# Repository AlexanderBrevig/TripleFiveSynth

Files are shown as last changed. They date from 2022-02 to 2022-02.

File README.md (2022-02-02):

# TripleFiveSynth

    Work In Progress!

A simple idea of using a 555 timer per note in a synth.

## `/src/main.rs`

This will generate appropriate capacitor and trim values for each note.

See the output in [tune_triple_fives.txt](https://raw.githubusercontent.com/alexanderbrevig/TripleFiveSynth/tune_triple_fives.txt) for details.

## 555 Configuration

The plan is to have one of these voices per note:
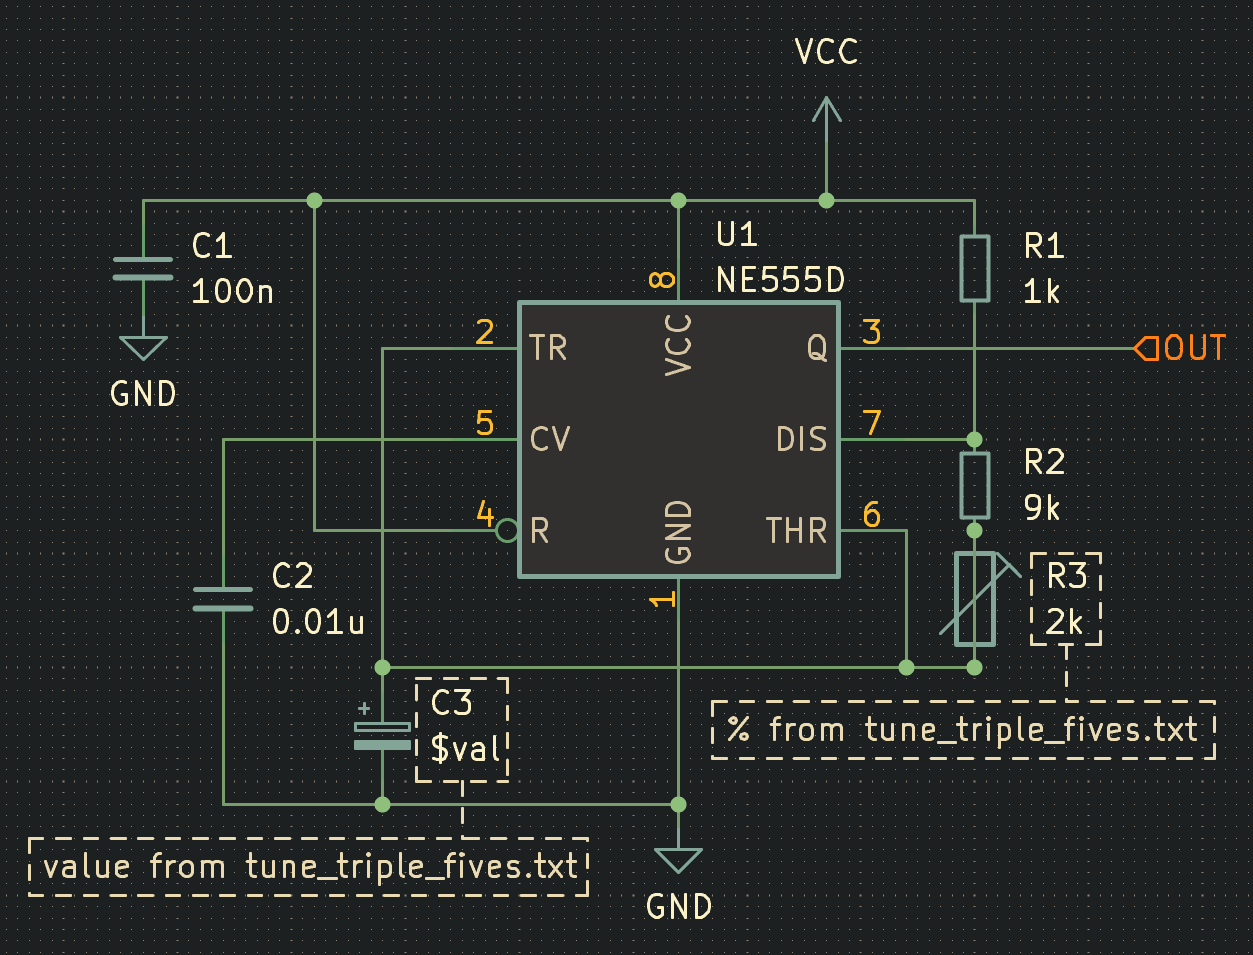
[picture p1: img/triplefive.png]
555 voice


## Example tuning for 440Hz

Per the line in `tune_triple_fives.txt` we get:

> 0440.00Hz => 150.00nF	Trim => 1431.9Ω -> 71.60%

This means, our `C3` should be `150nF`, and `R3` at approx `71.6%`.

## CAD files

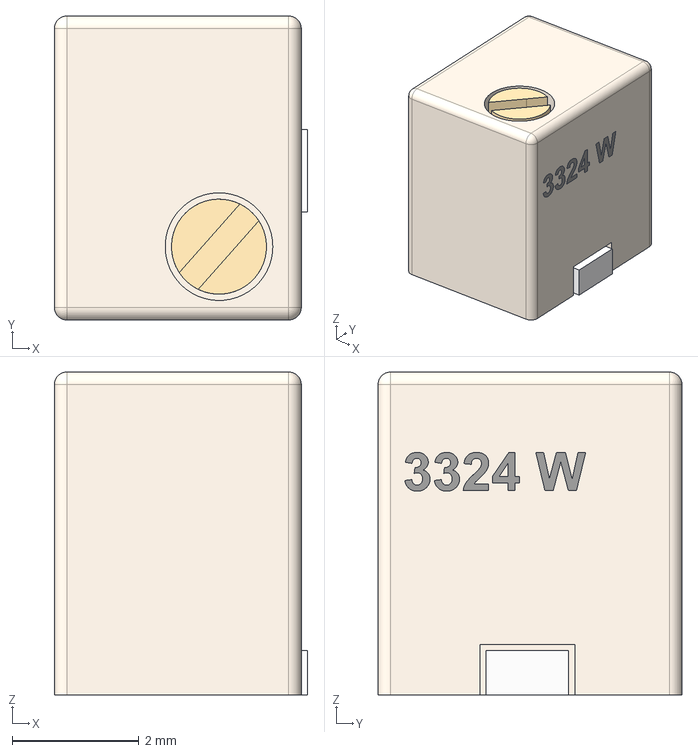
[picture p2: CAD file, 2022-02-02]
step/Bourns 3324W Trimpot.step
4.00 x 4.80 x 5.10 mm

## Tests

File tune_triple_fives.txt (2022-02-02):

0016.35Hz => 003.90uF	Trim => 1818.4Ω -> 90.92%
0017.32Hz => 003.90uF	Trim => 1184.3Ω -> 59.21%
0018.35Hz => 003.60uF	Trim => 1424.8Ω -> 71.24%
0019.45Hz => 003.30uF	Trim => 1743.8Ω -> 87.19%
0020.60Hz => 003.30uF	Trim => 1116.0Ω -> 55.80%
0021.83Hz => 003.00uF	Trim => 1519.4Ω -> 75.97%
0023.12Hz => 003.00uF	Trim => 0904.5Ω -> 45.23%
0024.50Hz => 002.70uF	Trim => 1409.2Ω -> 70.46%
0025.96Hz => 002.70uF	Trim => 0795.6Ω -> 39.78%
0027.50Hz => 002.40uF	Trim => 1433.8Ω -> 71.69%
0029.14Hz => 002.20uF	Trim => 1756.3Ω -> 87.82%
0030.87Hz => 002.20uF	Trim => 1125.4Ω -> 56.27%
0032.70Hz => 002.00uF	Trim => 1533.8Ω -> 76.69%
0034.65Hz => 002.00uF	Trim => 0912.7Ω -> 45.64%
0036.71Hz => 001.80uF	Trim => 1420.4Ω -> 71.02%
0038.89Hz => 001.80uF	Trim => 0808.1Ω -> 40.41%
0041.20Hz => 001.60uF	Trim => 1446.4Ω -> 72.32%
0043.65Hz => 001.50uF	Trim => 1520.7Ω -> 76.04%
0046.25Hz => 001.50uF	Trim => 0901.1Ω -> 45.06%
0049.00Hz => 001.30uF	Trim => 1827.6Ω -> 91.38%
0051.91Hz => 001.30uF	Trim => 1192.6Ω -> 59.63%
0055.00Hz => 001.20uF	Trim => 1432.8Ω -> 71.64%
0058.27Hz => 001.10uF	Trim => 1757.3Ω -> 87.87%
0061.74Hz => 001.10uF	Trim => 1124.6Ω -> 56.23%
0065.41Hz => 001.00uF	Trim => 1531.2Ω -> 76.56%
0069.30Hz => 001.00uF	Trim => 0912.0Ω -> 45.60%
0069.30Hz => 910.00nF	Trim => 1941.7Ω -> 97.09%
0073.42Hz => 001.00uF	Trim => 0327.7Ω -> 16.39%
0073.42Hz => 910.00nF	Trim => 1299.6Ω -> 64.98%
0077.78Hz => 820.00nF	Trim => 1813.1Ω -> 90.66%
0082.41Hz => 820.00nF	Trim => 1177.4Ω -> 58.87%
0087.31Hz => 750.00nF	Trim => 1518.8Ω -> 75.94%
0092.50Hz => 680.00nF	Trim => 1971.2Ω -> 98.56%
0098.00Hz => 680.00nF	Trim => 1327.3Ω -> 66.37%
0103.83Hz => 620.00nF	Trim => 1708.3Ω -> 85.42%
0110.00Hz => 620.00nF	Trim => 1079.6Ω -> 53.98%
0116.54Hz => 560.00nF	Trim => 1555.8Ω -> 77.79%
0123.47Hz => 510.00nF	Trim => 1958.3Ω -> 97.92%
0130.81Hz => 510.00nF	Trim => 1315.3Ω -> 65.77%
0138.59Hz => 470.00nF	Trim => 1577.0Ω -> 78.85%
0146.83Hz => 430.00nF	Trim => 1927.9Ω -> 96.40%
0155.56Hz => 430.00nF	Trim => 1286.5Ω -> 64.33%
0164.81Hz => 390.00nF	Trim => 1725.3Ω -> 86.27%
0174.61Hz => 360.00nF	Trim => 1978.3Ω -> 98.92%
0185.00Hz => 360.00nF	Trim => 1333.6Ω -> 66.68%
0196.00Hz => 330.00nF	Trim => 1655.2Ω -> 82.76%
0207.65Hz => 330.00nF	Trim => 1029.3Ω -> 51.46%
0220.00Hz => 300.00nF	Trim => 1432.0Ω -> 71.60%
0233.08Hz => 270.00nF	Trim => 1965.0Ω -> 98.25%
0246.94Hz => 270.00nF	Trim => 1321.5Ω -> 66.07%
0261.63Hz => 240.00nF	Trim => 1990.6Ω -> 99.53%
0277.18Hz => 240.00nF	Trim => 1346.0Ω -> 67.30%
0293.66Hz => 220.00nF	Trim => 1668.0Ω -> 83.40%
0311.13Hz => 220.00nF	Trim => 1040.9Ω -> 52.05%
0329.63Hz => 200.00nF	Trim => 1444.2Ω -> 72.21%
0349.23Hz => 180.00nF	Trim => 1977.8Ω -> 98.89%
0369.99Hz => 180.00nF	Trim => 1333.7Ω -> 66.69%
0392.00Hz => 180.00nF	Trim => 0725.4Ω -> 36.27%
0415.30Hz => 160.00nF	Trim => 1358.2Ω -> 67.91%
0440.00Hz => 150.00nF	Trim => 1431.9Ω -> 71.60%
0466.16Hz => 150.00nF	Trim => 0818.4Ω -> 40.92%
0493.88Hz => 130.00nF	Trim => 1737.6Ω -> 86.88%
0523.25Hz => 120.00nF	Trim => 1990.8Ω -> 99.54%
0554.37Hz => 120.00nF	Trim => 1345.7Ω -> 67.29%
0587.33Hz => 110.00nF	Trim => 1667.7Ω -> 83.39%
0622.25Hz => 110.00nF	Trim => 1041.0Ω -> 52.05%
0659.25Hz => 100.00nF	Trim => 1444.3Ω -> 72.22%
0698.46Hz => 091.00nF	Trim => 1851.5Ω -> 92.58%
0698.46Hz => 100.00nF	Trim => 0829.9Ω -> 41.50%
0739.99Hz => 091.00nF	Trim => 1214.5Ω -> 60.73%
0739.99Hz => 100.00nF	Trim => 0250.2Ω -> 12.51%
0783.99Hz => 082.00nF	Trim => 1723.1Ω -> 86.16%
0830.61Hz => 082.00nF	Trim => 1093.2Ω -> 54.66%
0880.00Hz => 075.00nF	Trim => 1431.8Ω -> 71.59%
0932.33Hz => 068.00nF	Trim => 1880.4Ω -> 94.02%
0987.77Hz => 068.00nF	Trim => 1241.7Ω -> 62.09%
1046.50Hz => 062.00nF	Trim => 1620.0Ω -> 81.00%
1108.73Hz => 062.00nF	Trim => 0995.9Ω -> 49.80%
1174.66Hz => 056.00nF	Trim => 1468.2Ω -> 73.41%
1244.51Hz => 051.00nF	Trim => 1867.6Ω -> 93.38%
1318.51Hz => 051.00nF	Trim => 1229.6Ω -> 61.48%
1396.91Hz => 047.00nF	Trim => 1489.3Ω -> 74.46%
1479.98Hz => 043.00nF	Trim => 1837.4Ω -> 91.87%
1567.98Hz => 043.00nF	Trim => 1201.1Ω -> 60.05%
1661.22Hz => 039.00nF	Trim => 1636.4Ω -> 81.82%
1760.00Hz => 036.00nF	Trim => 1887.3Ω -> 94.37%
1864.66Hz => 036.00nF	Trim => 1248.2Ω -> 62.41%
1975.53Hz => 033.00nF	Trim => 1567.2Ω -> 78.36%
2093.00Hz => 030.00nF	Trim => 1990.7Ω -> 99.54%
2217.46Hz => 030.00nF	Trim => 1345.8Ω -> 67.29%
2349.32Hz => 027.00nF	Trim => 1874.5Ω -> 93.73%
2489.02Hz => 027.00nF	Trim => 1236.1Ω -> 61.81%
2637.02Hz => 024.00nF	Trim => 1900.2Ω -> 95.01%
2793.83Hz => 024.00nF	Trim => 1260.3Ω -> 63.02%
2959.96Hz => 022.00nF	Trim => 1579.7Ω -> 78.99%
3135.96Hz => 022.00nF	Trim => 0957.9Ω -> 47.90%
3322.44Hz => 020.00nF	Trim => 1358.0Ω -> 67.90%
3520.00Hz => 018.00nF	Trim => 1887.3Ω -> 94.37%
3729.31Hz => 018.00nF	Trim => 1248.2Ω -> 62.41%
3951.07Hz => 016.00nF	Trim => 1913.1Ω -> 95.65%
4186.01Hz => 015.00nF	Trim => 1990.7Ω -> 99.54%
4434.92Hz => 015.00nF	Trim => 1345.8Ω -> 67.29%
4698.63Hz => 015.00nF	Trim => 0737.0Ω -> 36.85%
4978.03Hz => 013.00nF	Trim => 1649.0Ω -> 82.45%
5274.04Hz => 012.00nF	Trim => 1900.2Ω -> 95.01%
5587.65Hz => 012.00nF	Trim => 1260.3Ω -> 63.02%
5919.91Hz => 011.00nF	Trim => 1579.7Ω -> 78.99%
6271.93Hz => 011.00nF	Trim => 0957.9Ω -> 47.90%
6644.88Hz => 010.00nF	Trim => 1358.0Ω -> 67.90%
7040.00Hz => 009.10nF	Trim => 1762.2Ω -> 88.11%
7040.00Hz => 010.00nF	Trim => 0748.6Ω -> 37.43%
7458.62Hz => 009.10nF	Trim => 1130.1Ω -> 56.50%
7458.62Hz => 010.00nF	Trim => 0173.4Ω -> 08.67%
7902.13Hz => 008.20nF	Trim => 1634.7Ω -> 81.74%

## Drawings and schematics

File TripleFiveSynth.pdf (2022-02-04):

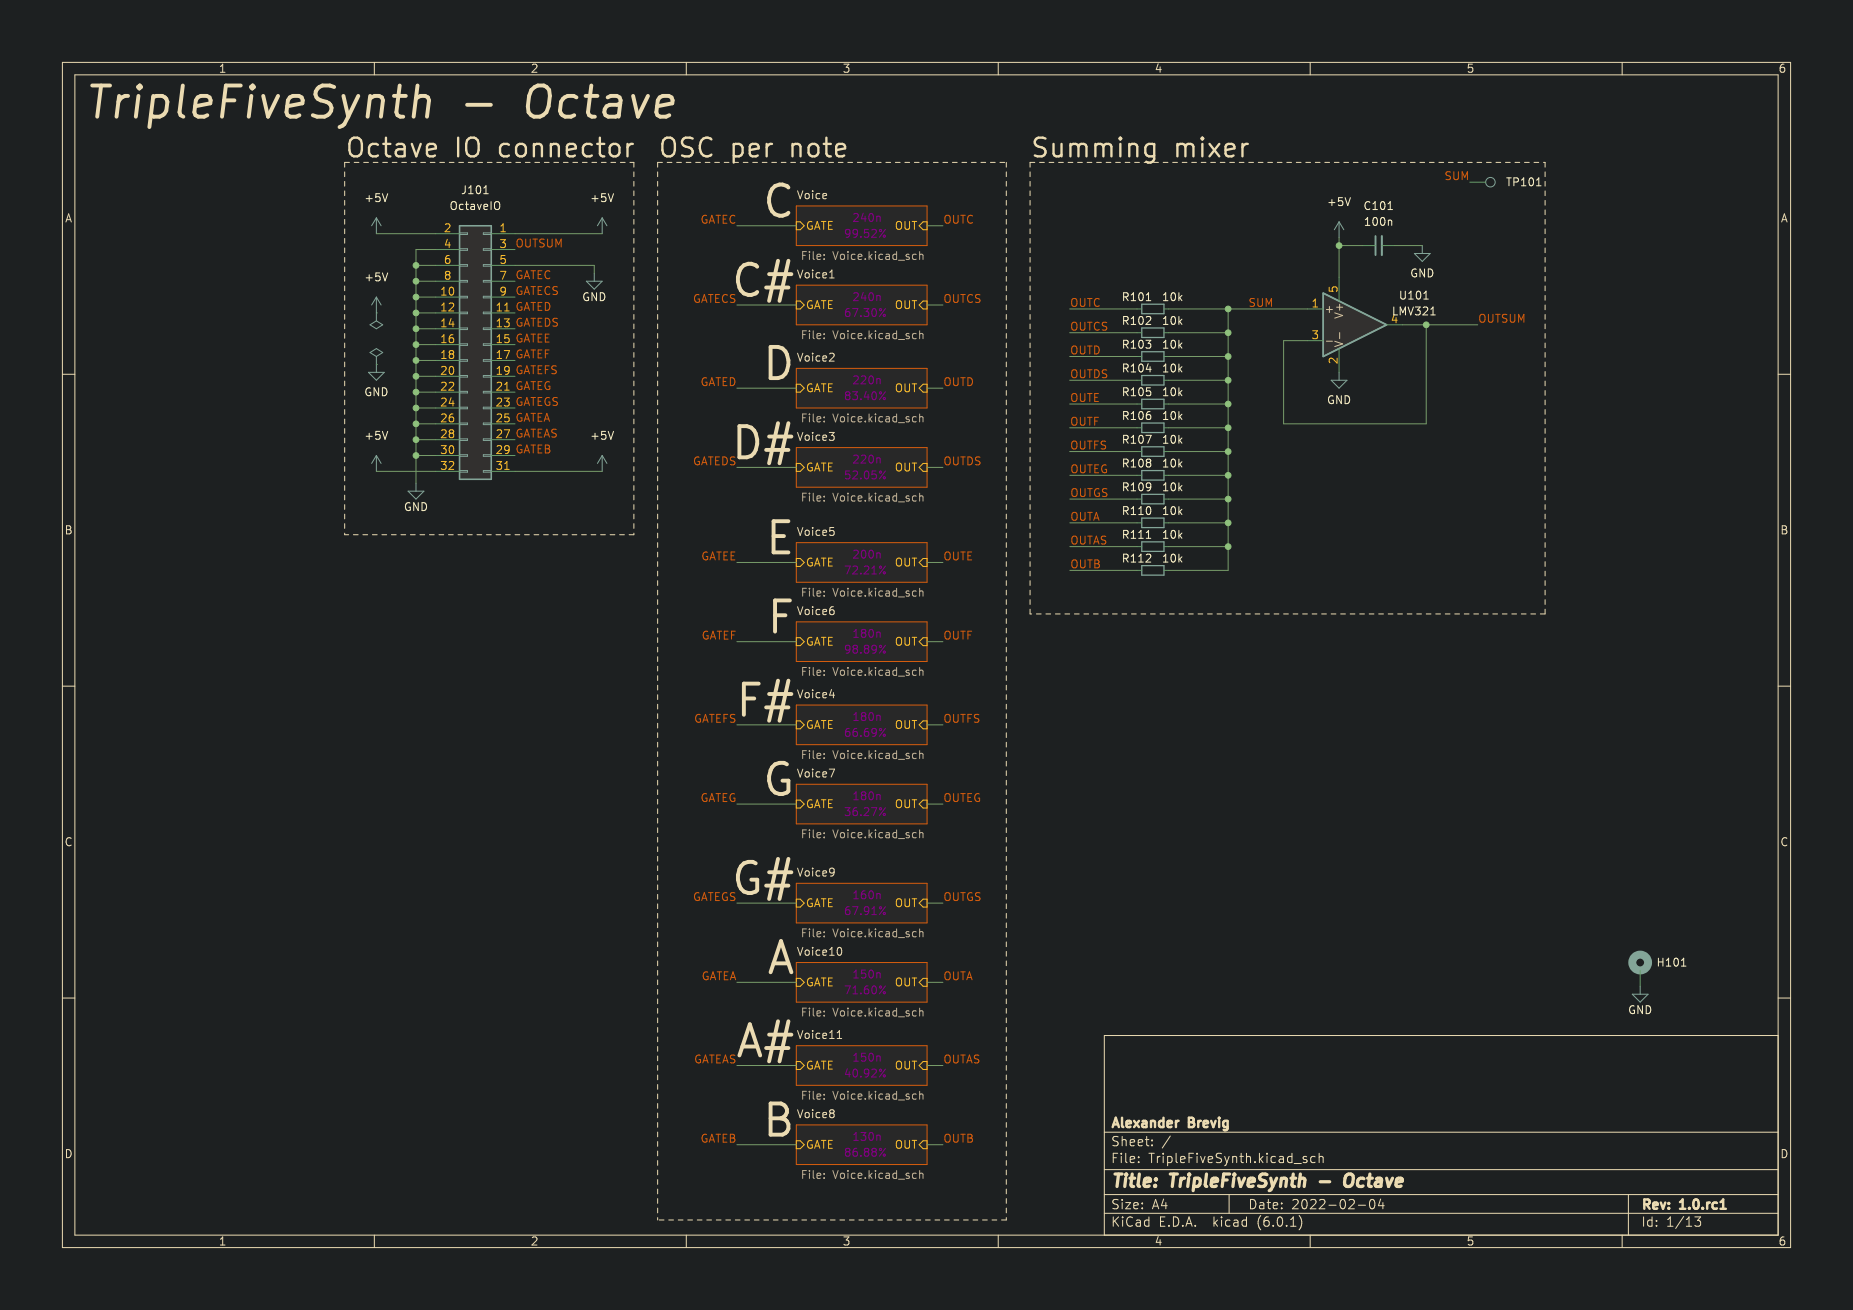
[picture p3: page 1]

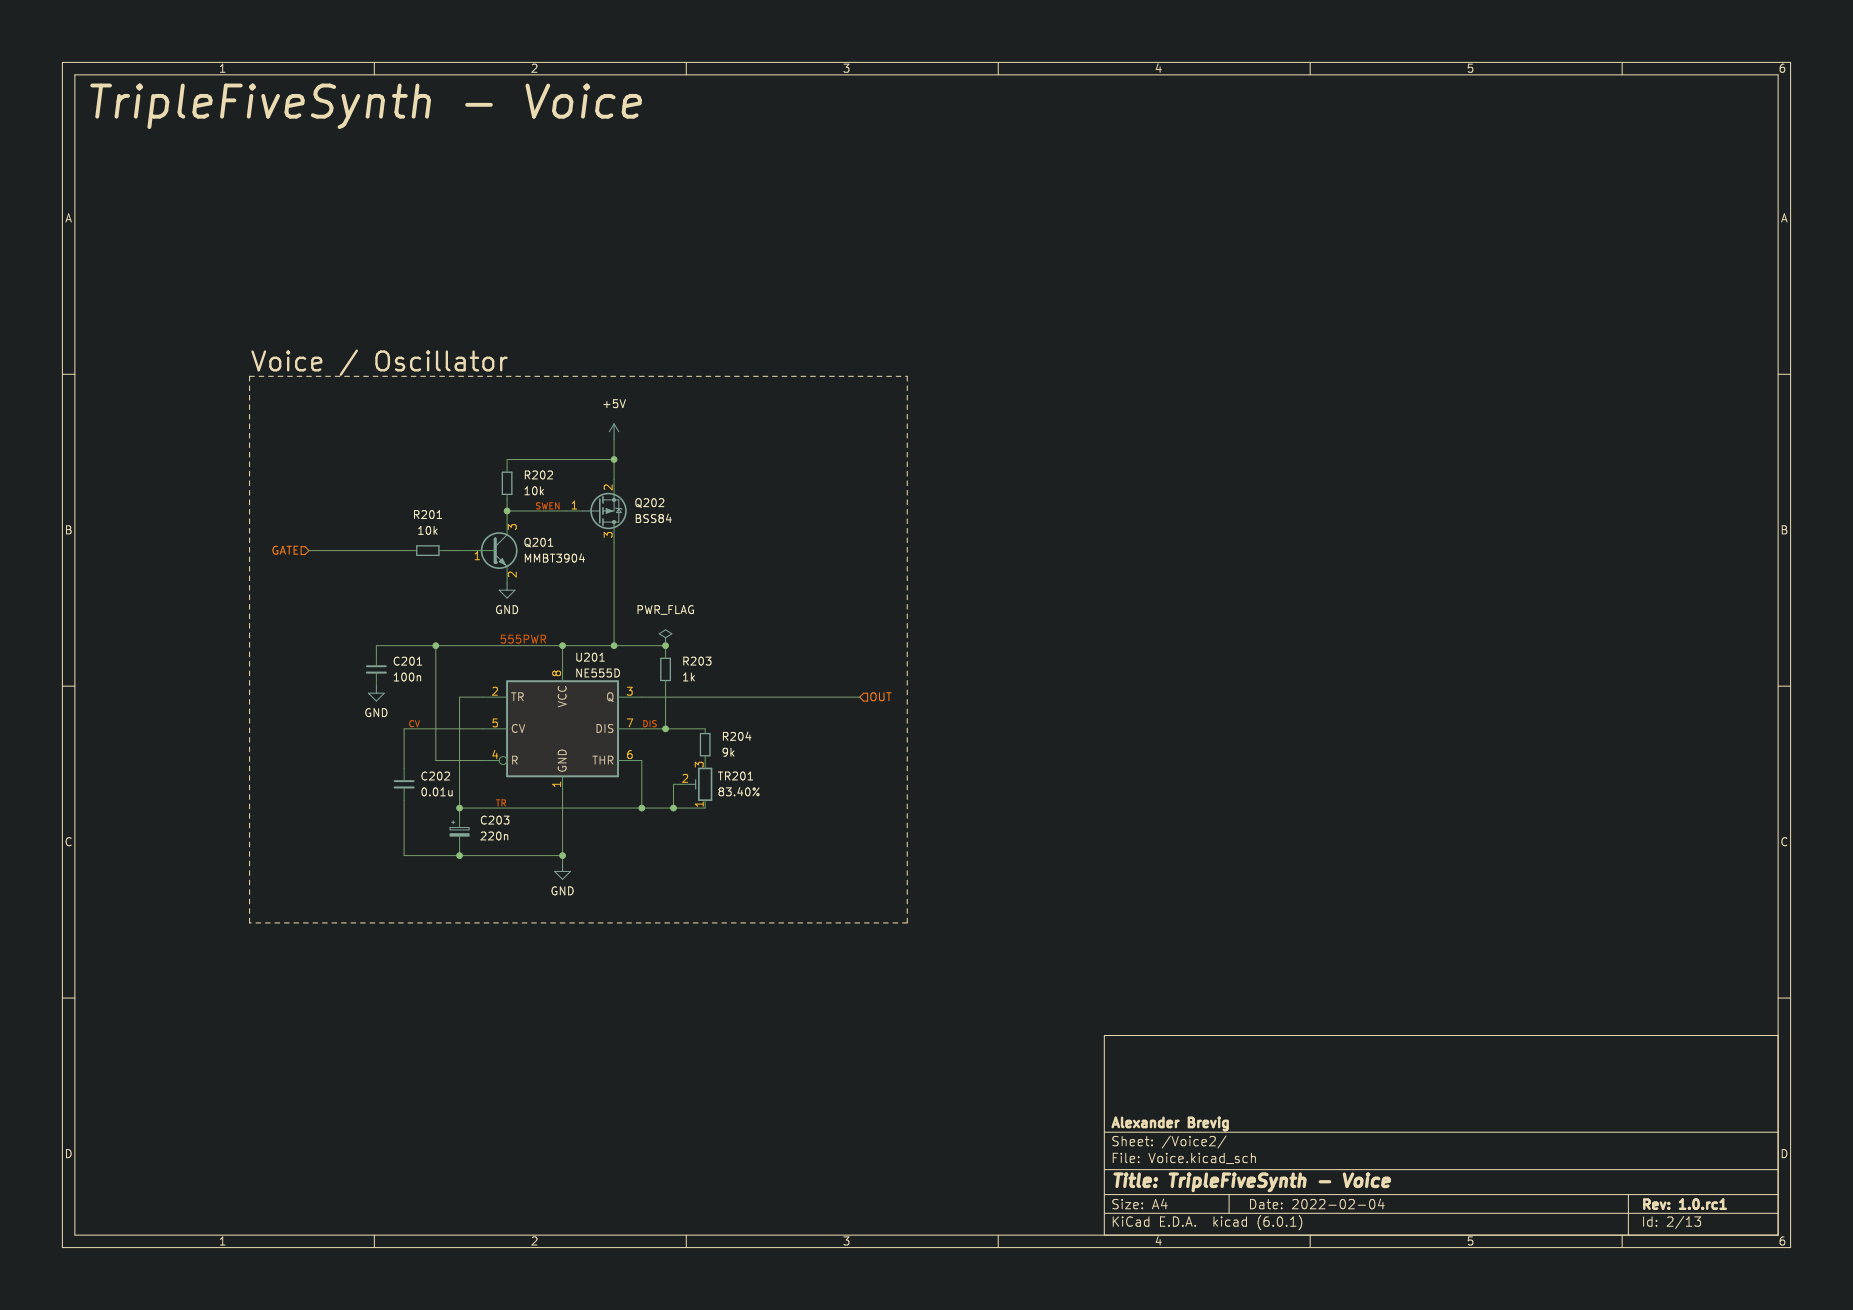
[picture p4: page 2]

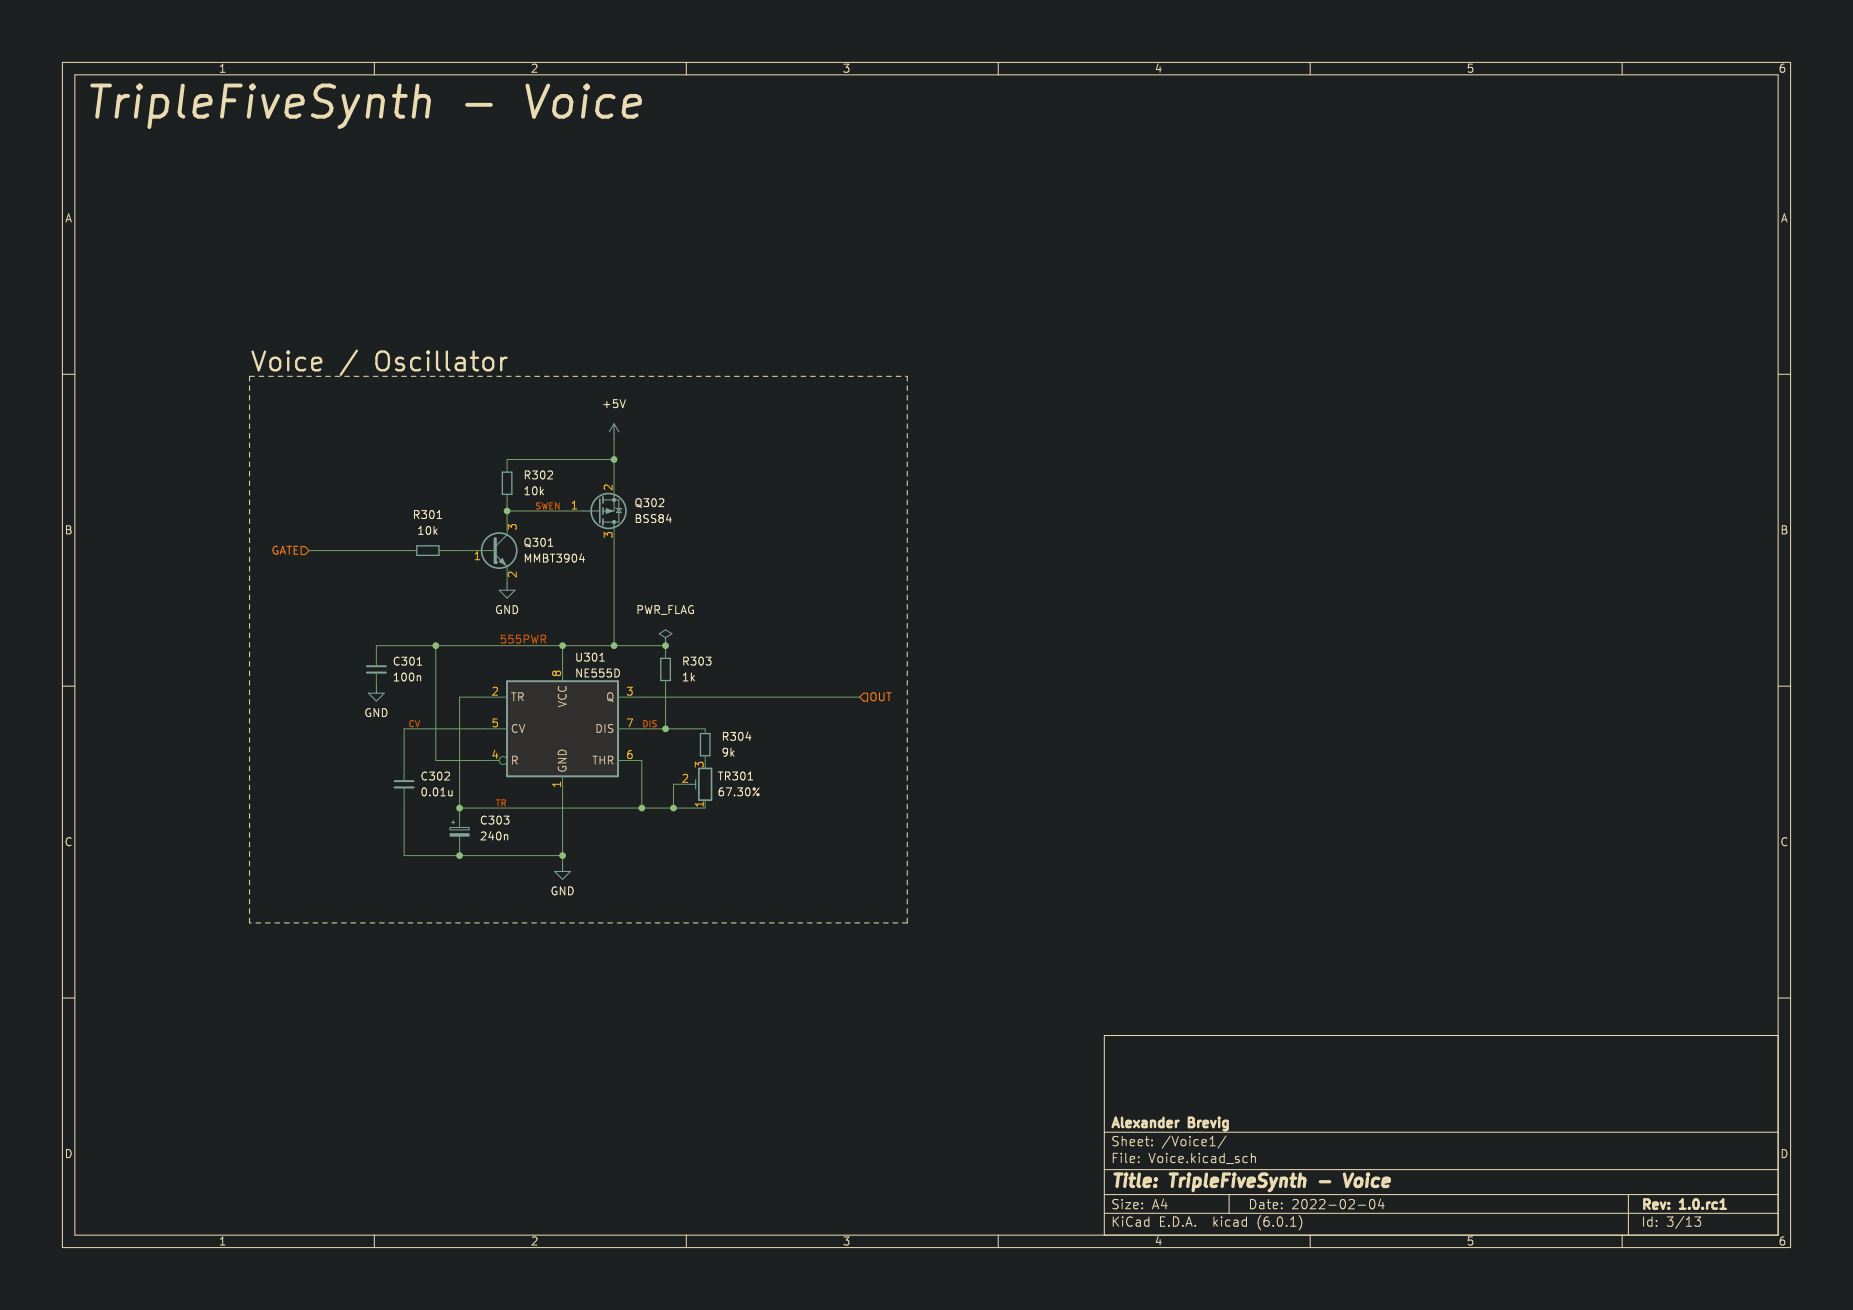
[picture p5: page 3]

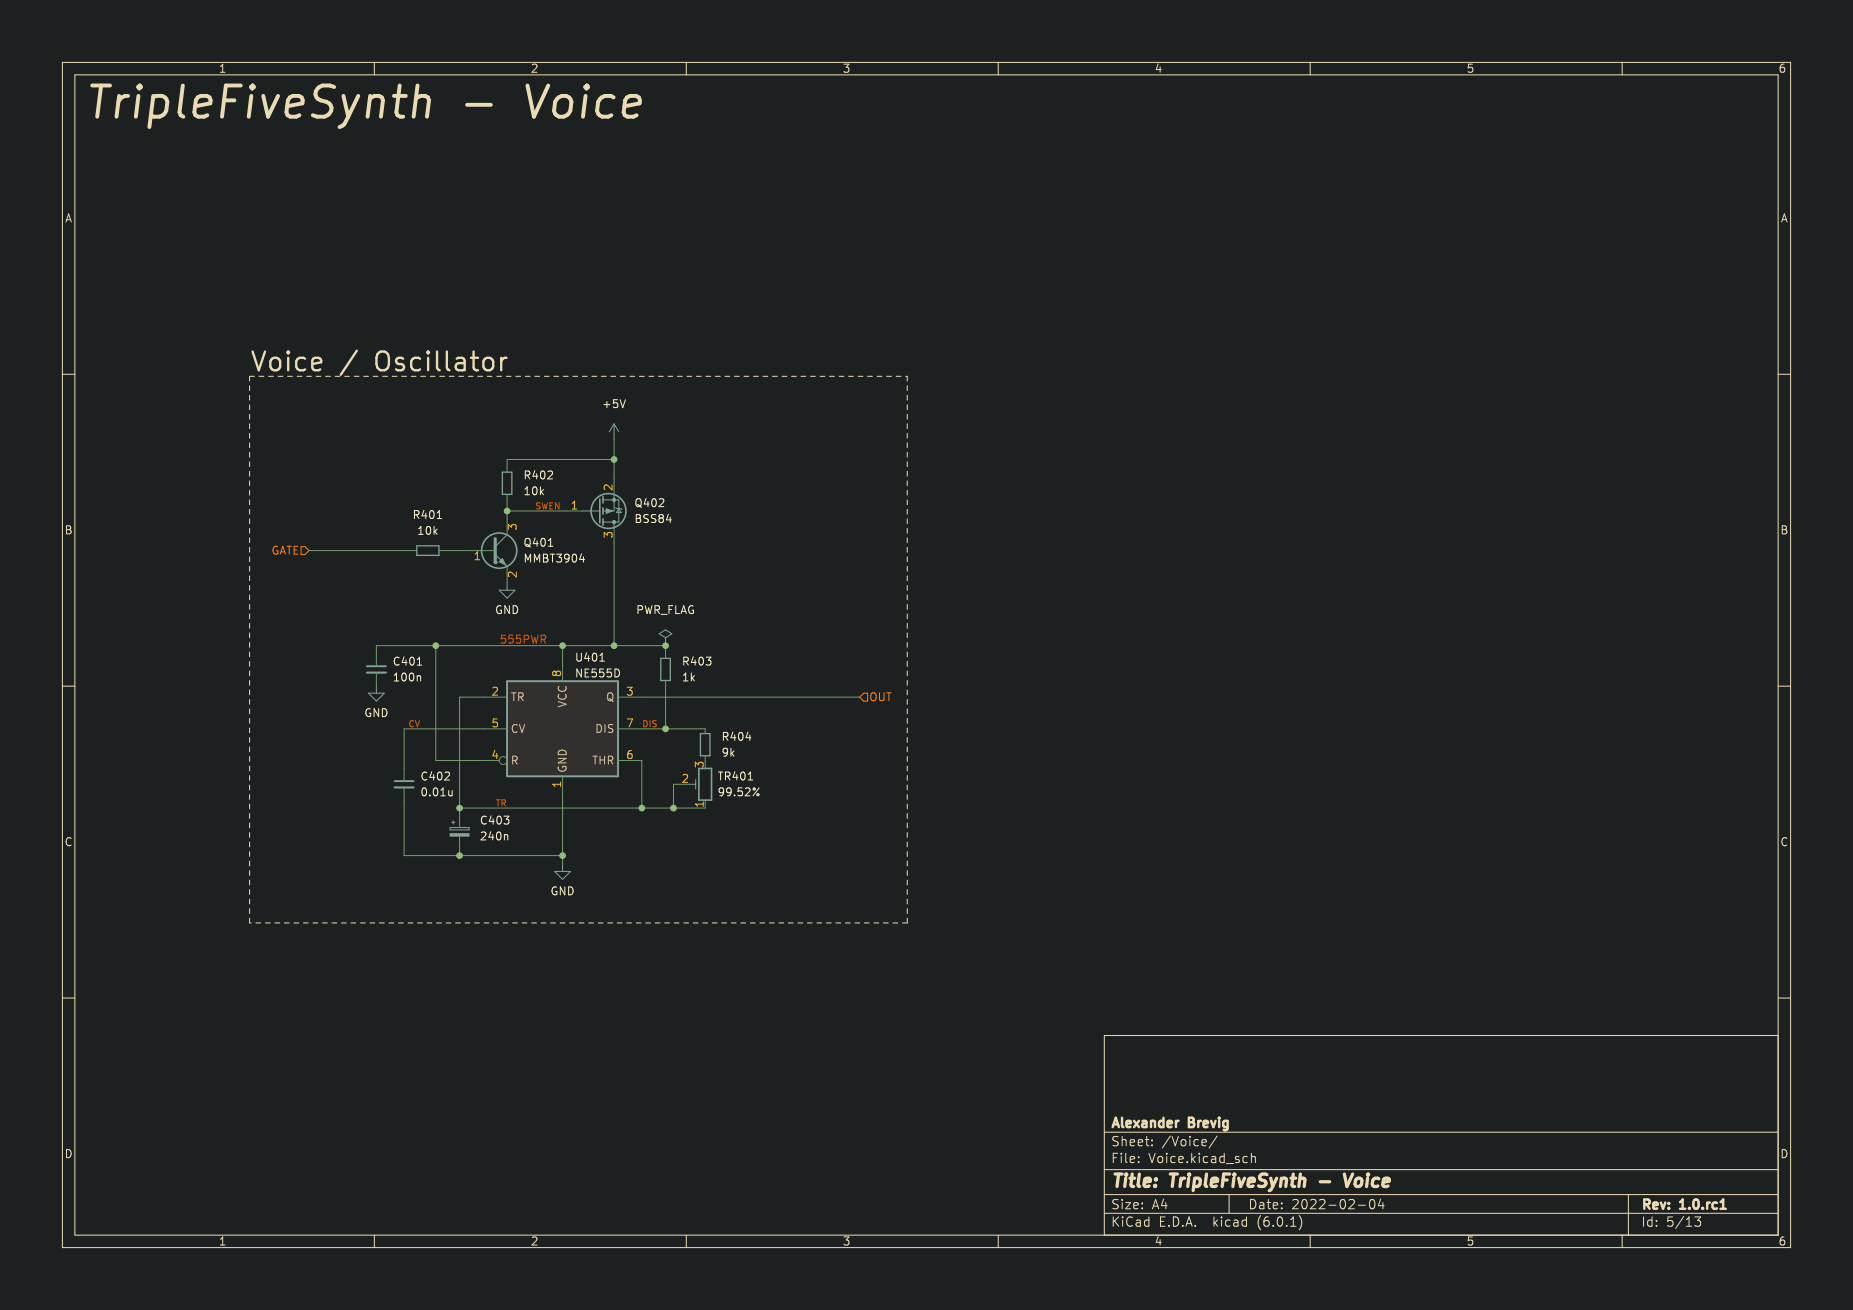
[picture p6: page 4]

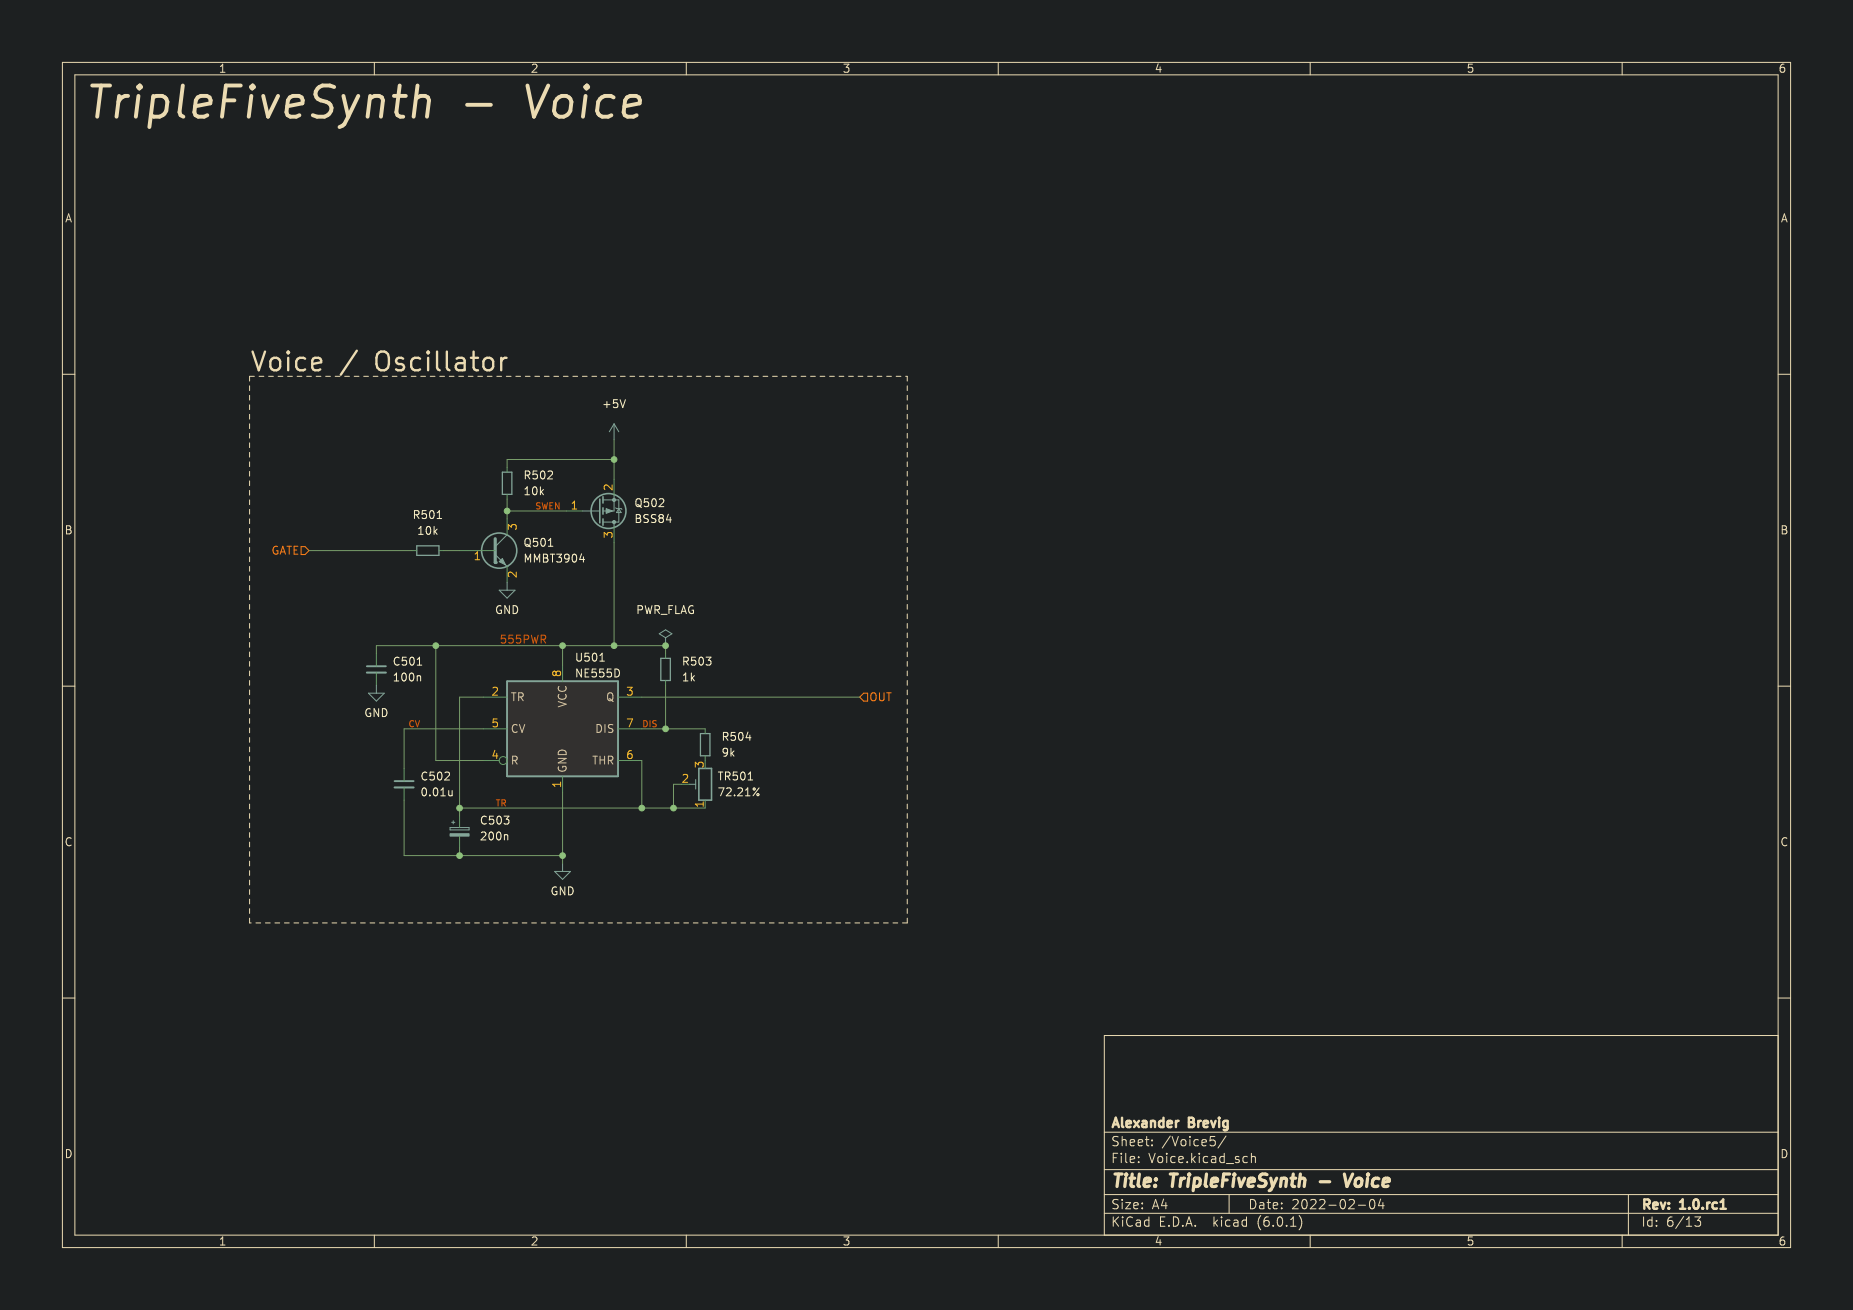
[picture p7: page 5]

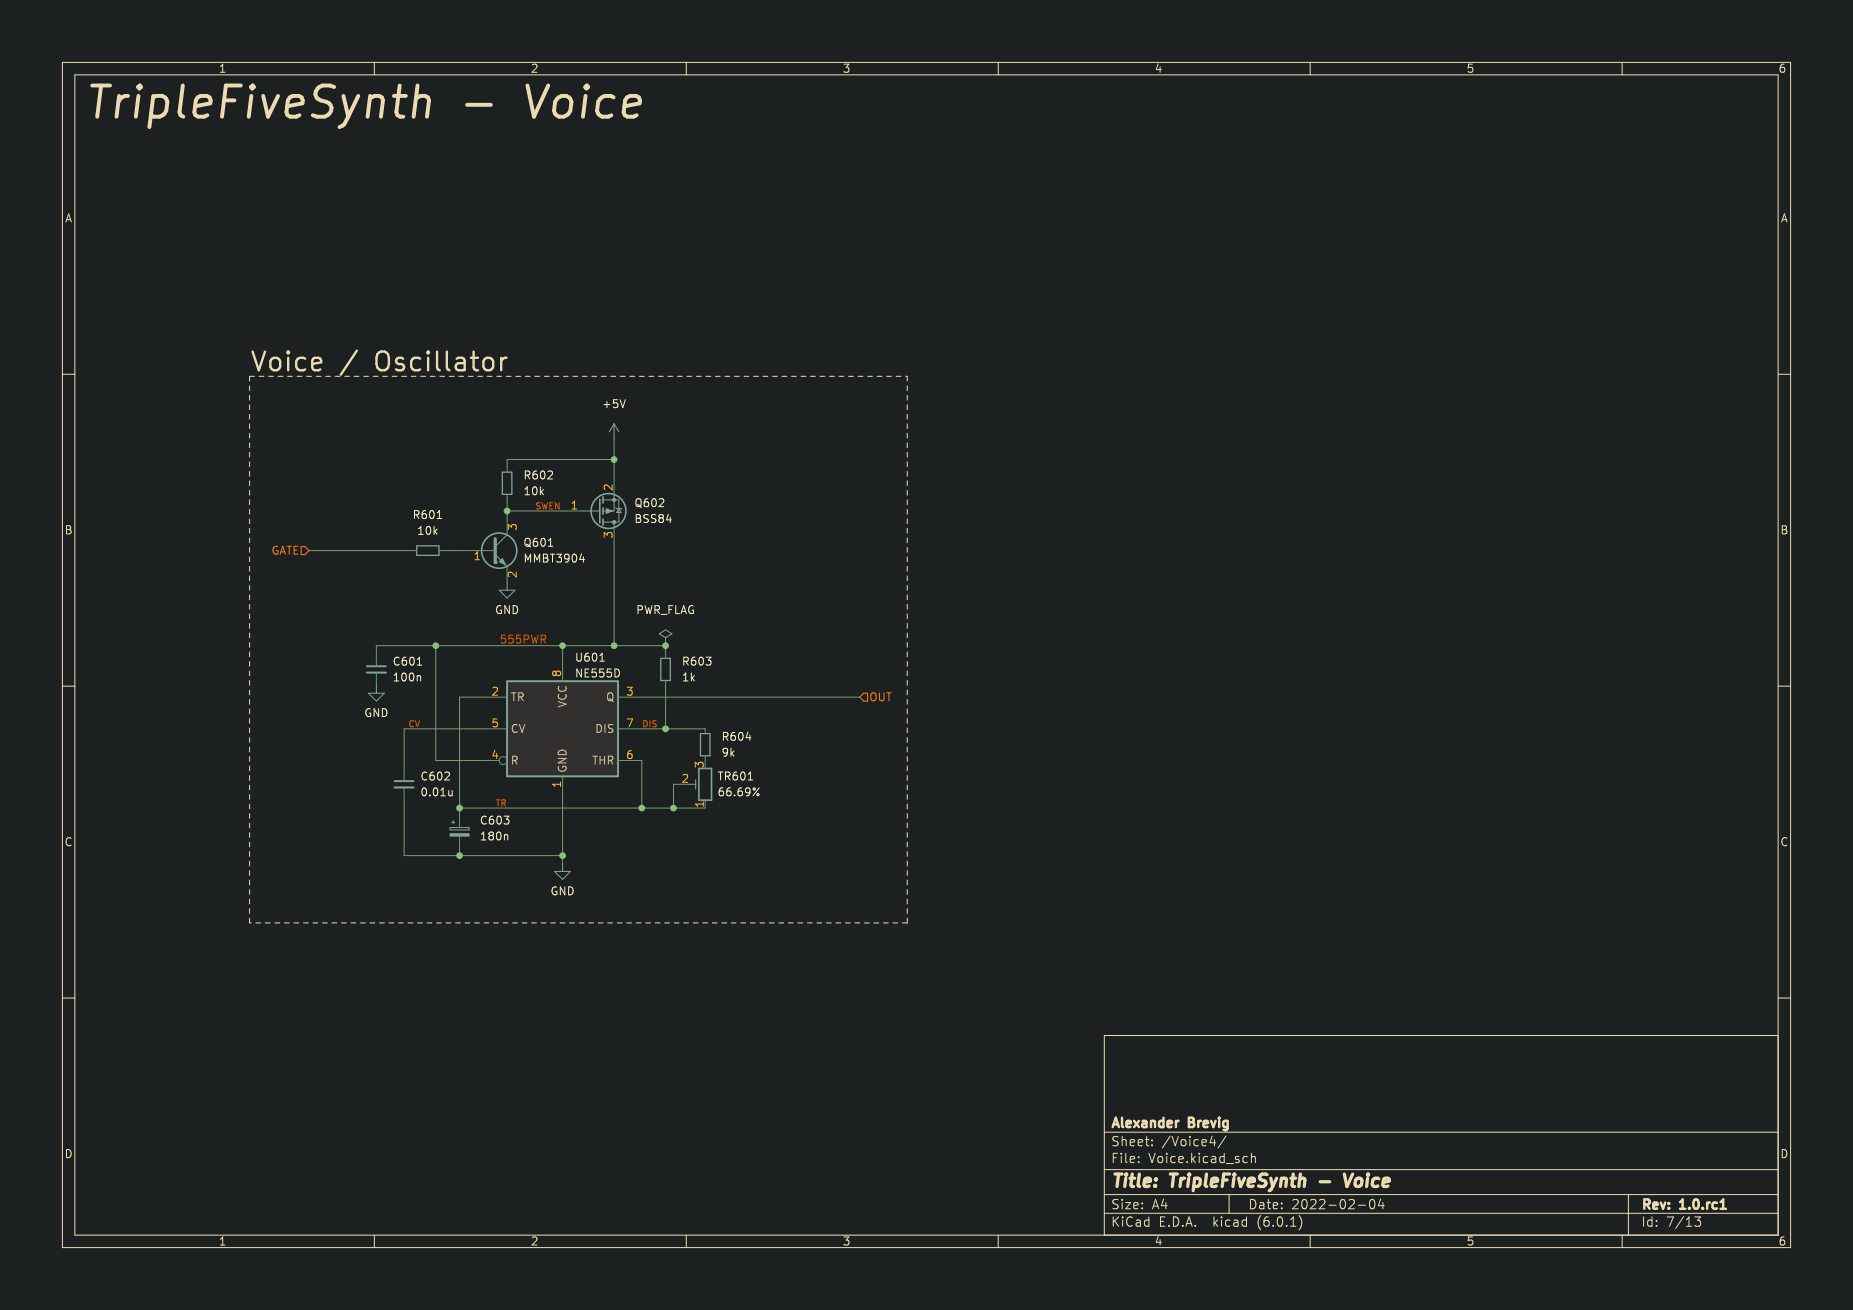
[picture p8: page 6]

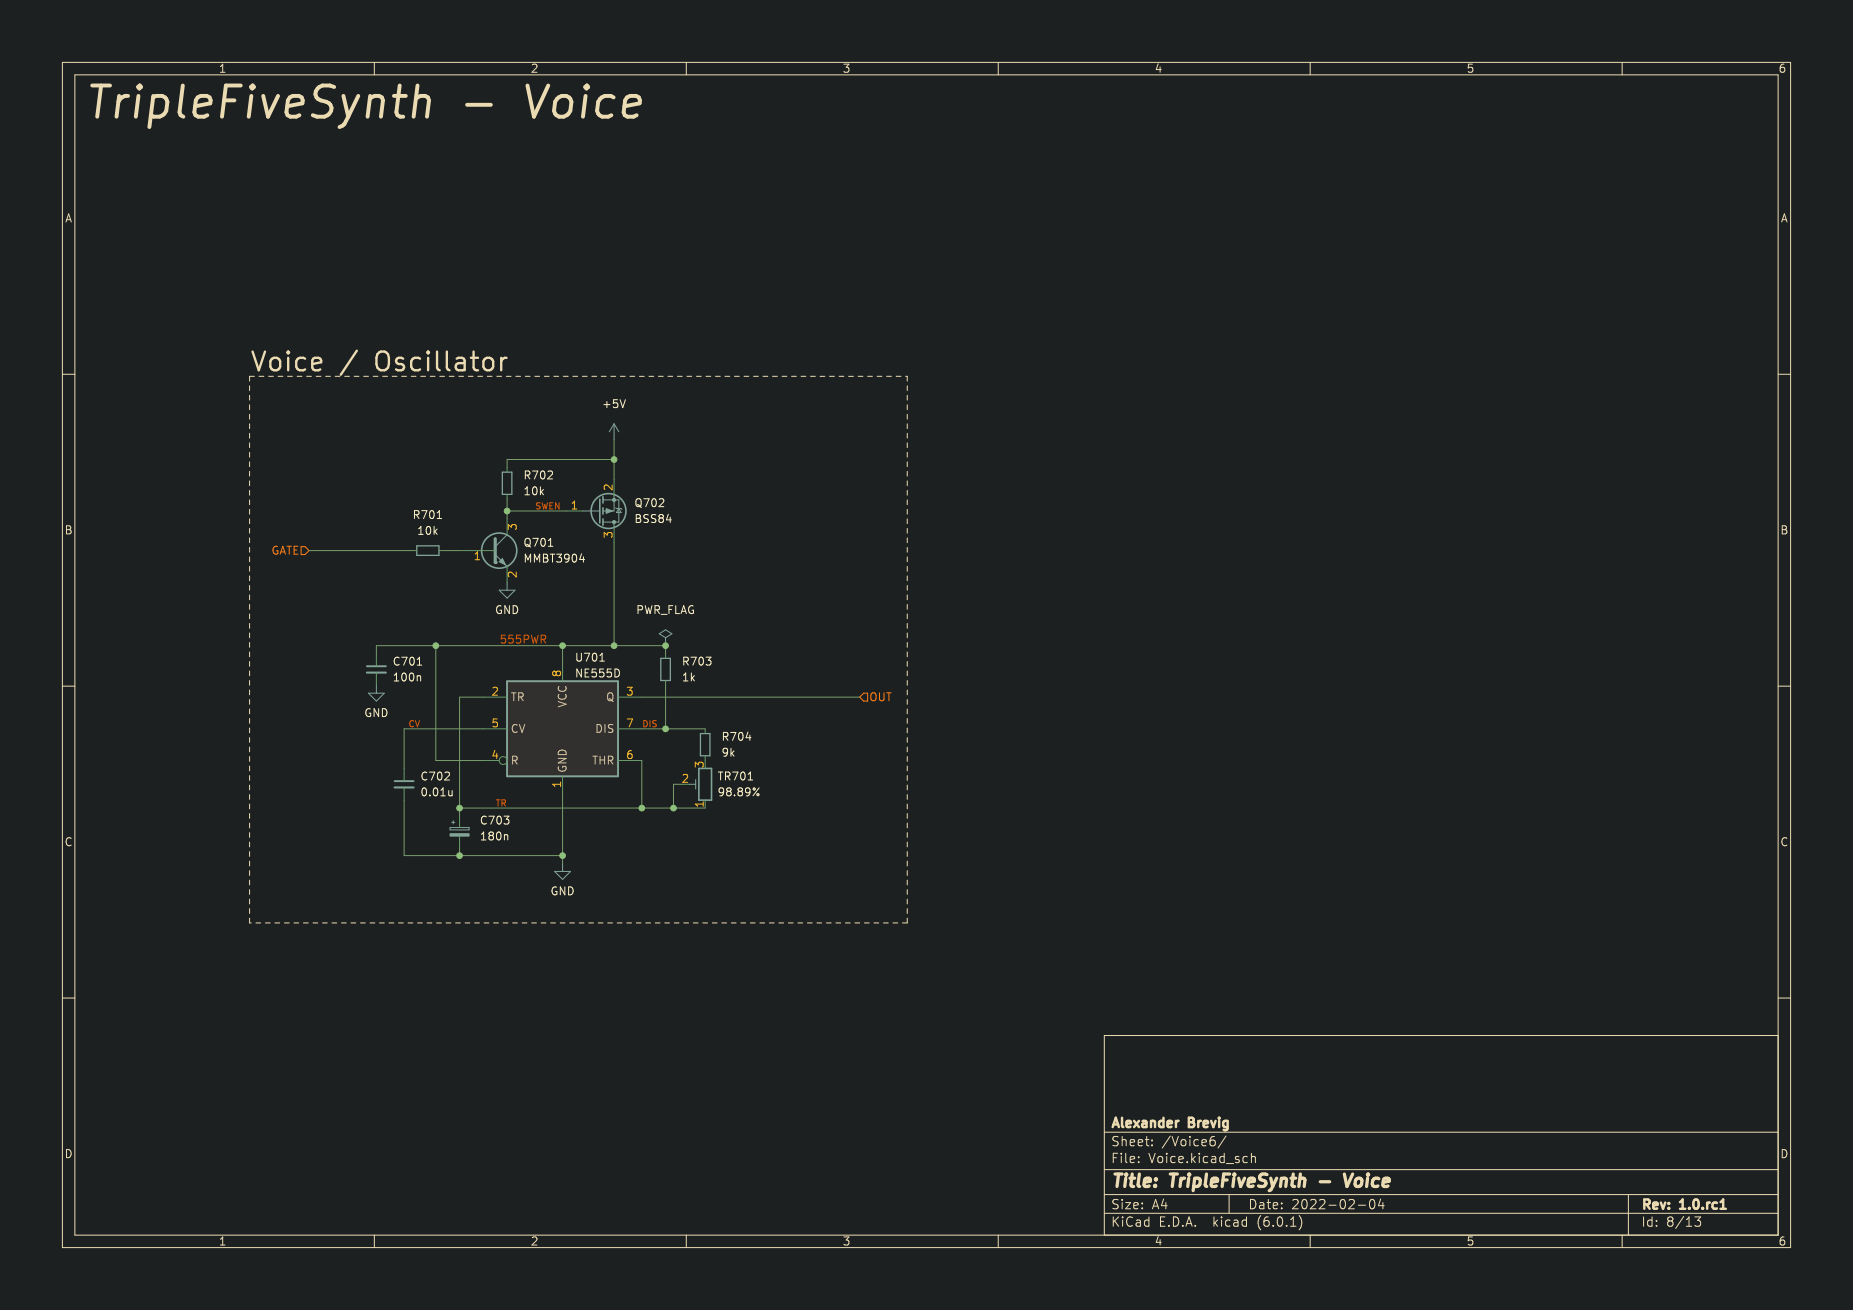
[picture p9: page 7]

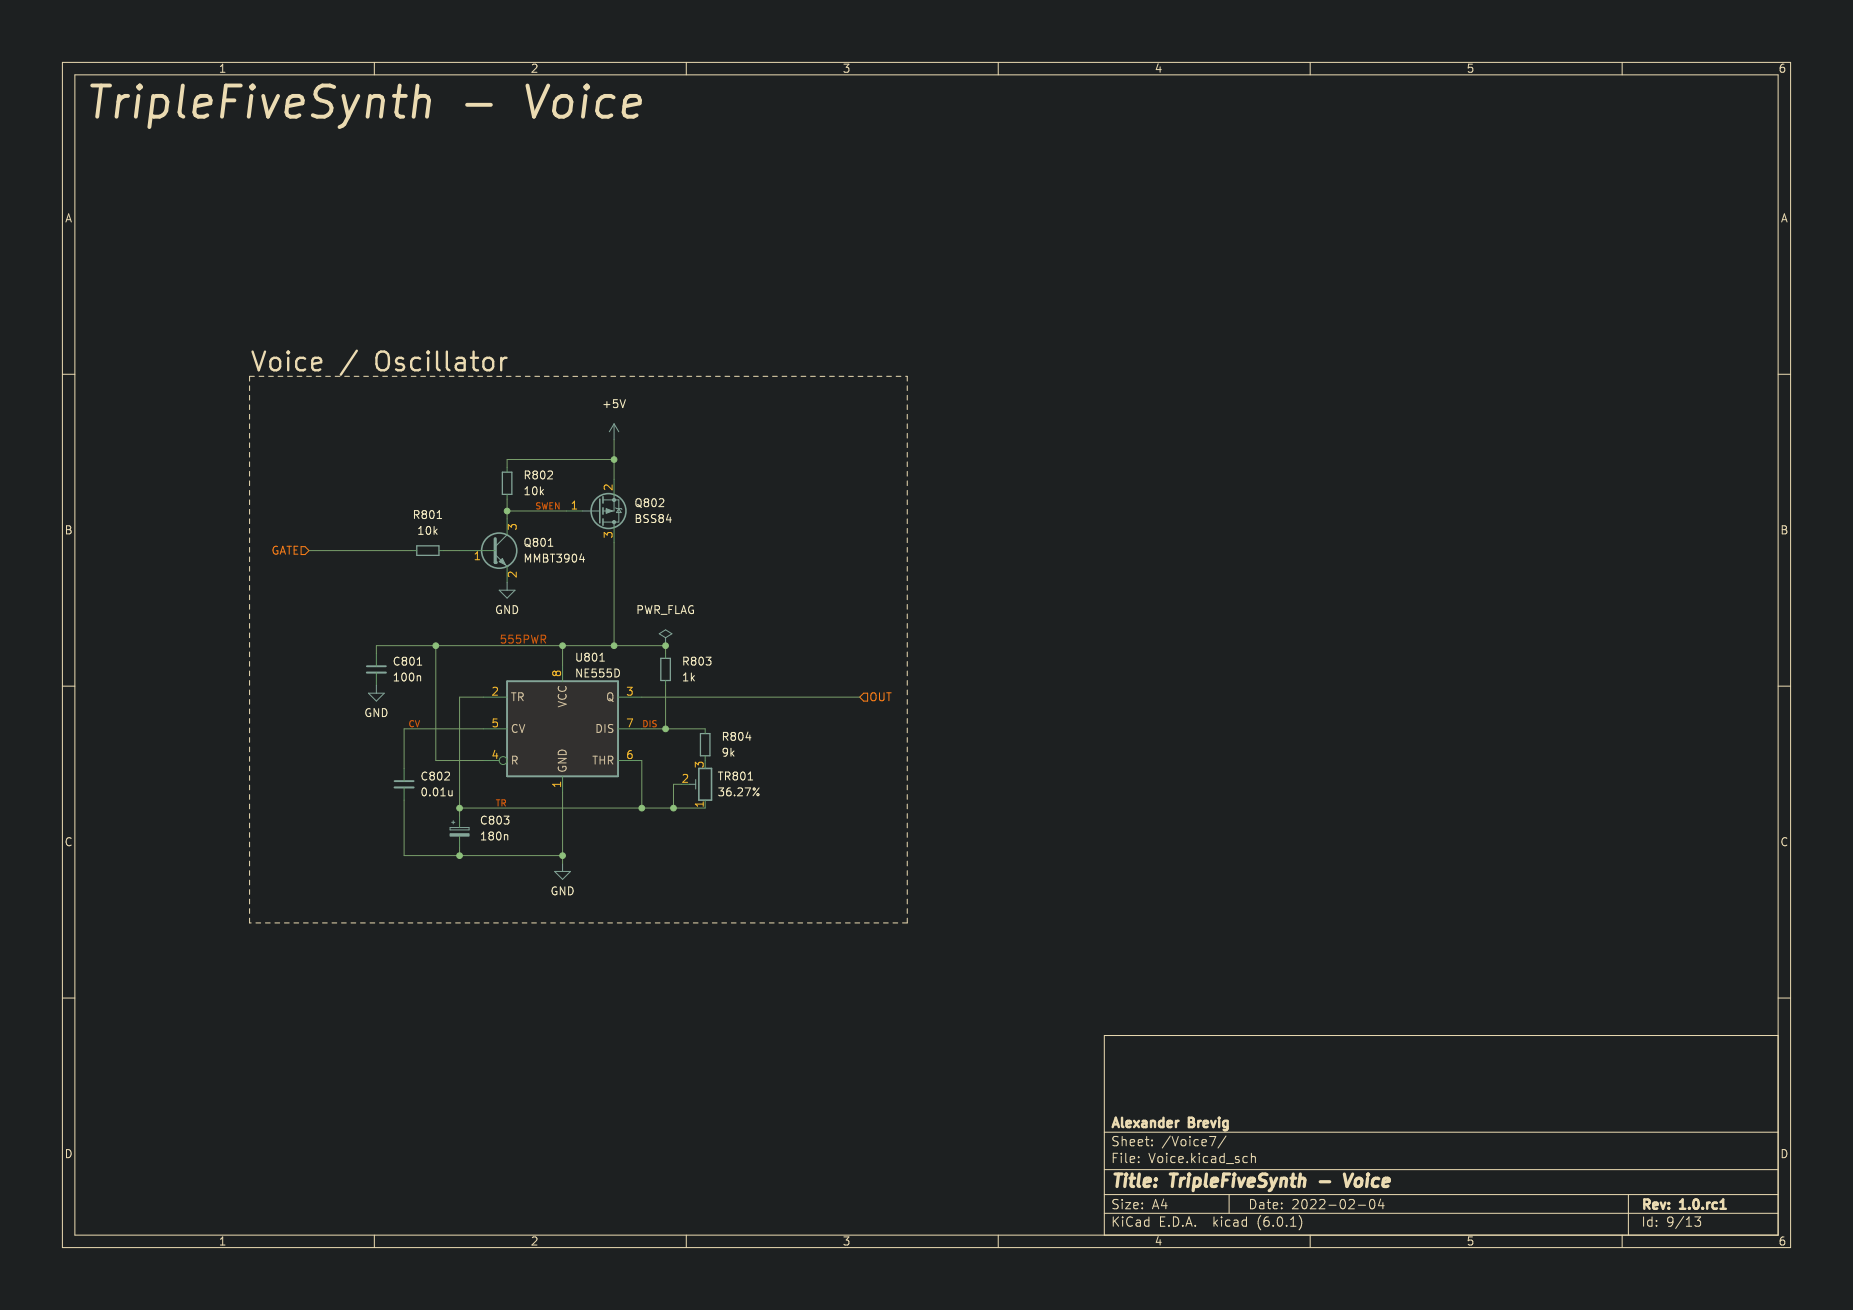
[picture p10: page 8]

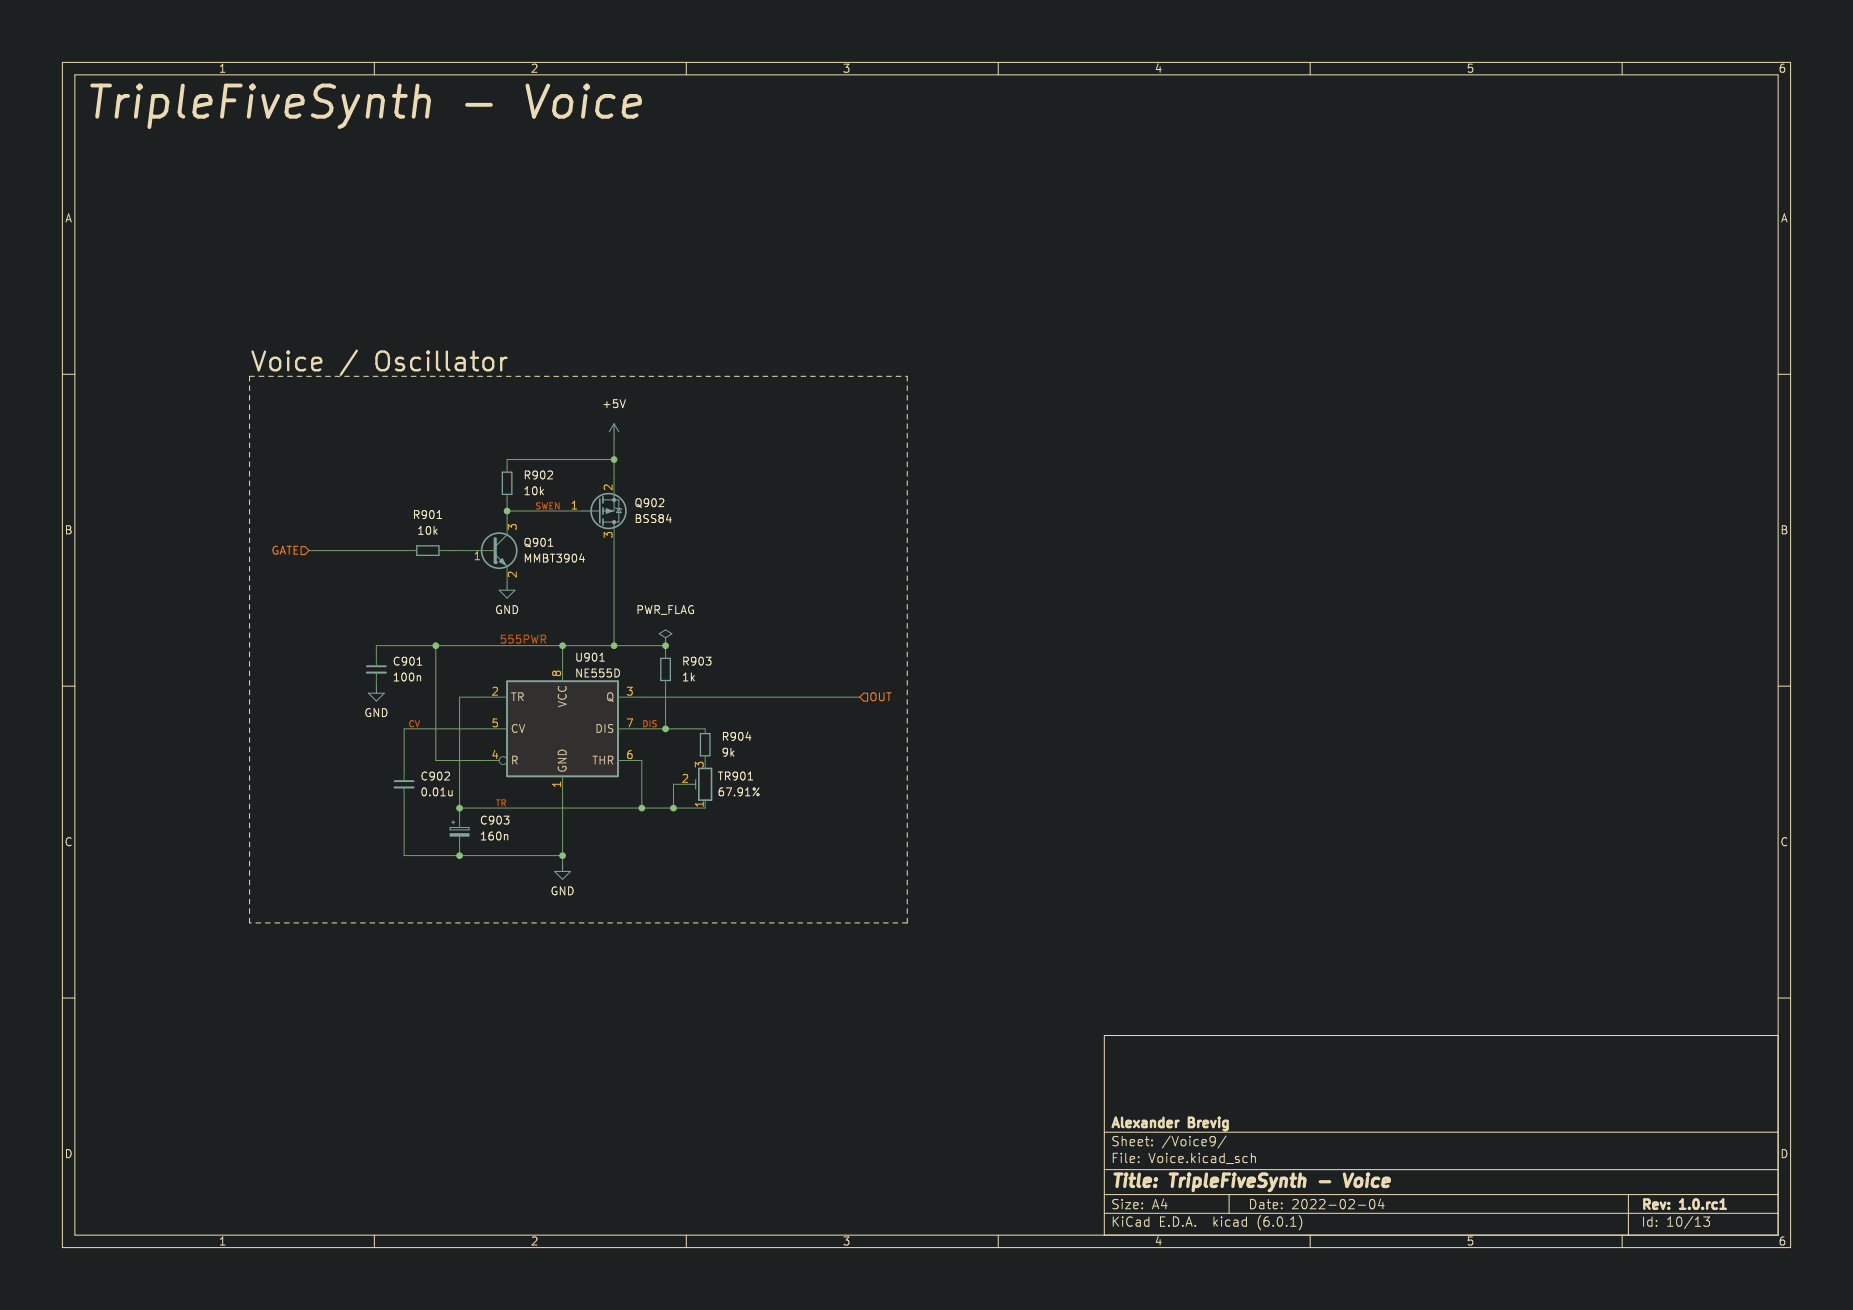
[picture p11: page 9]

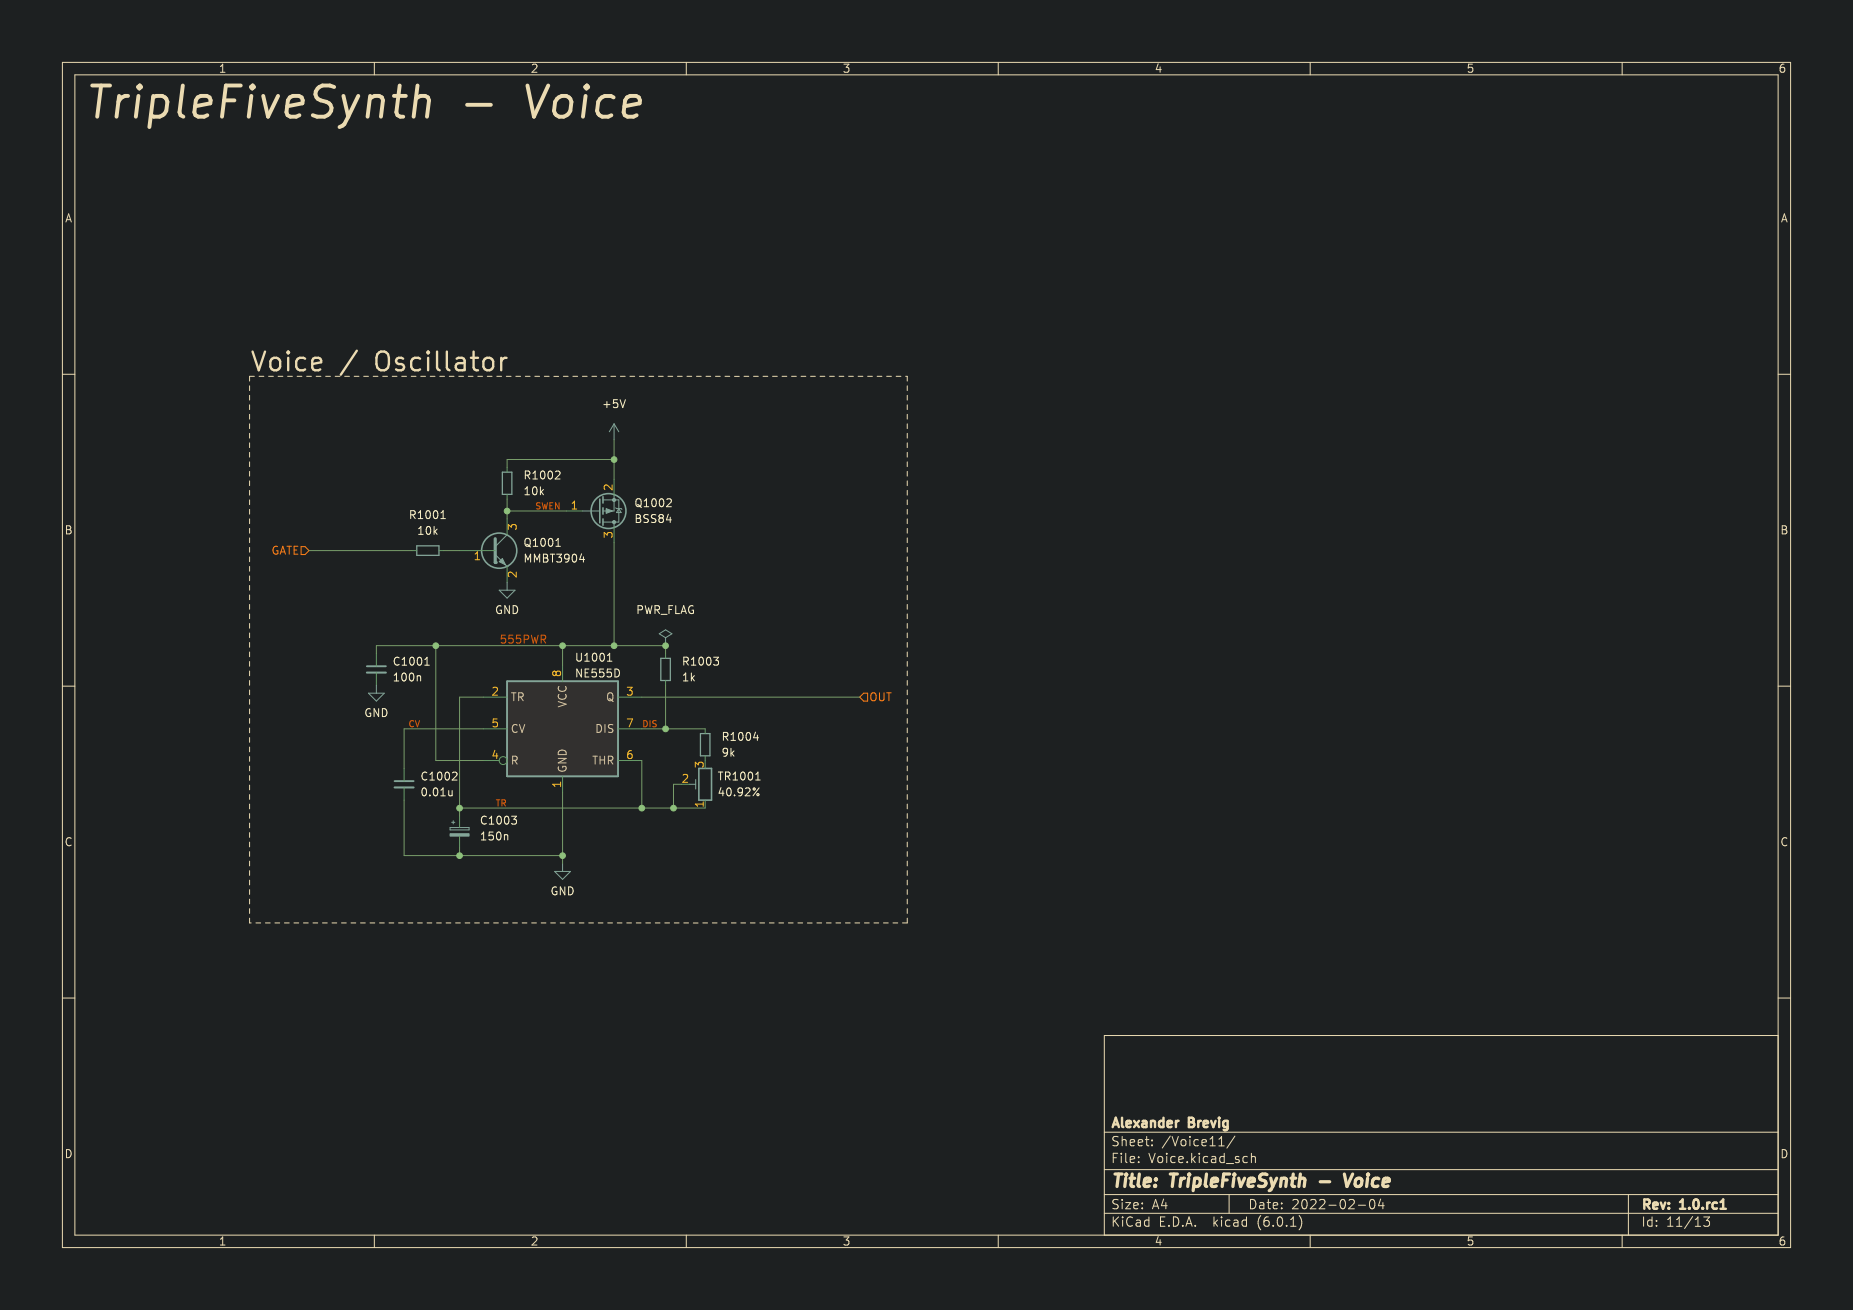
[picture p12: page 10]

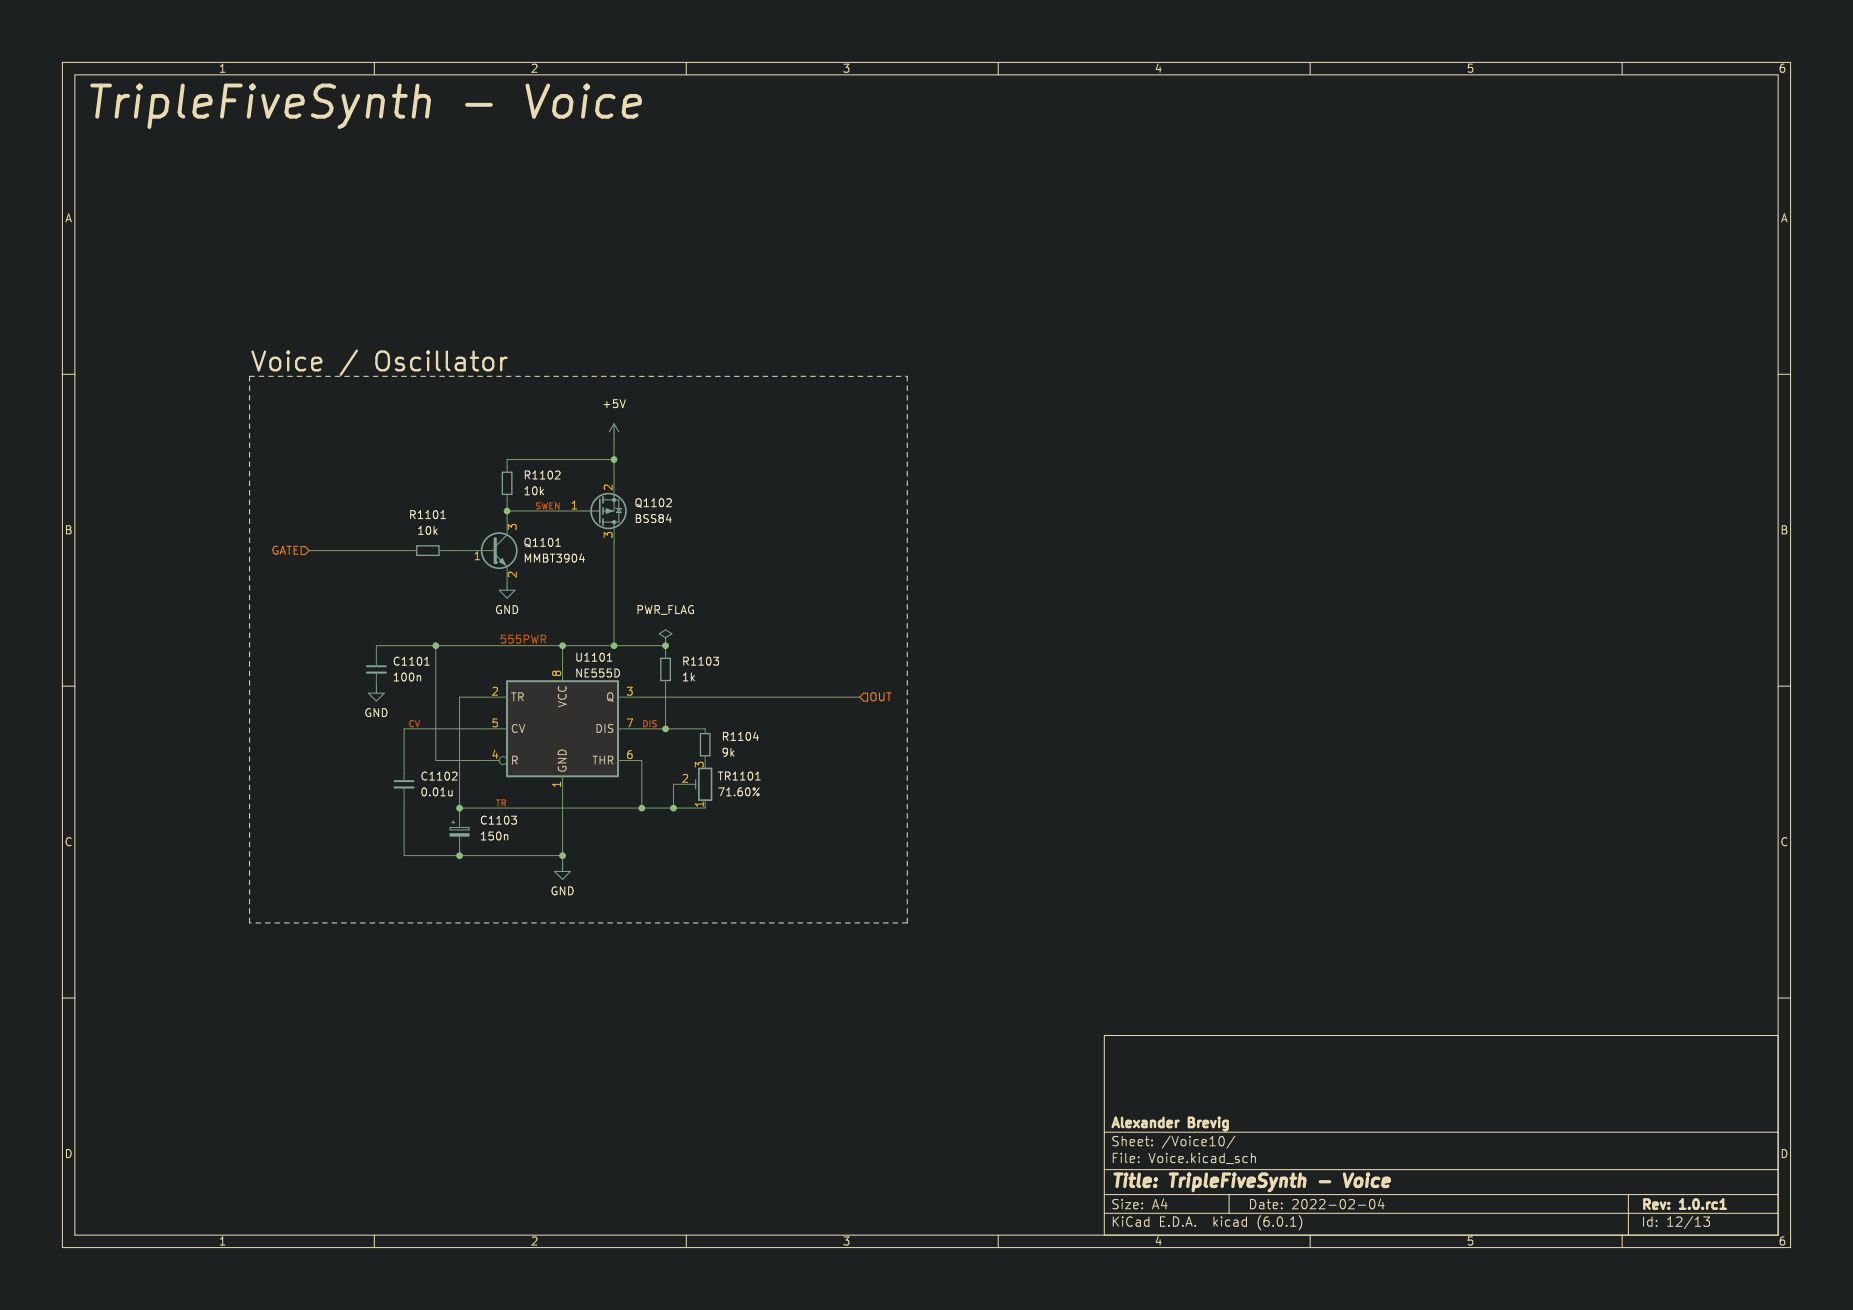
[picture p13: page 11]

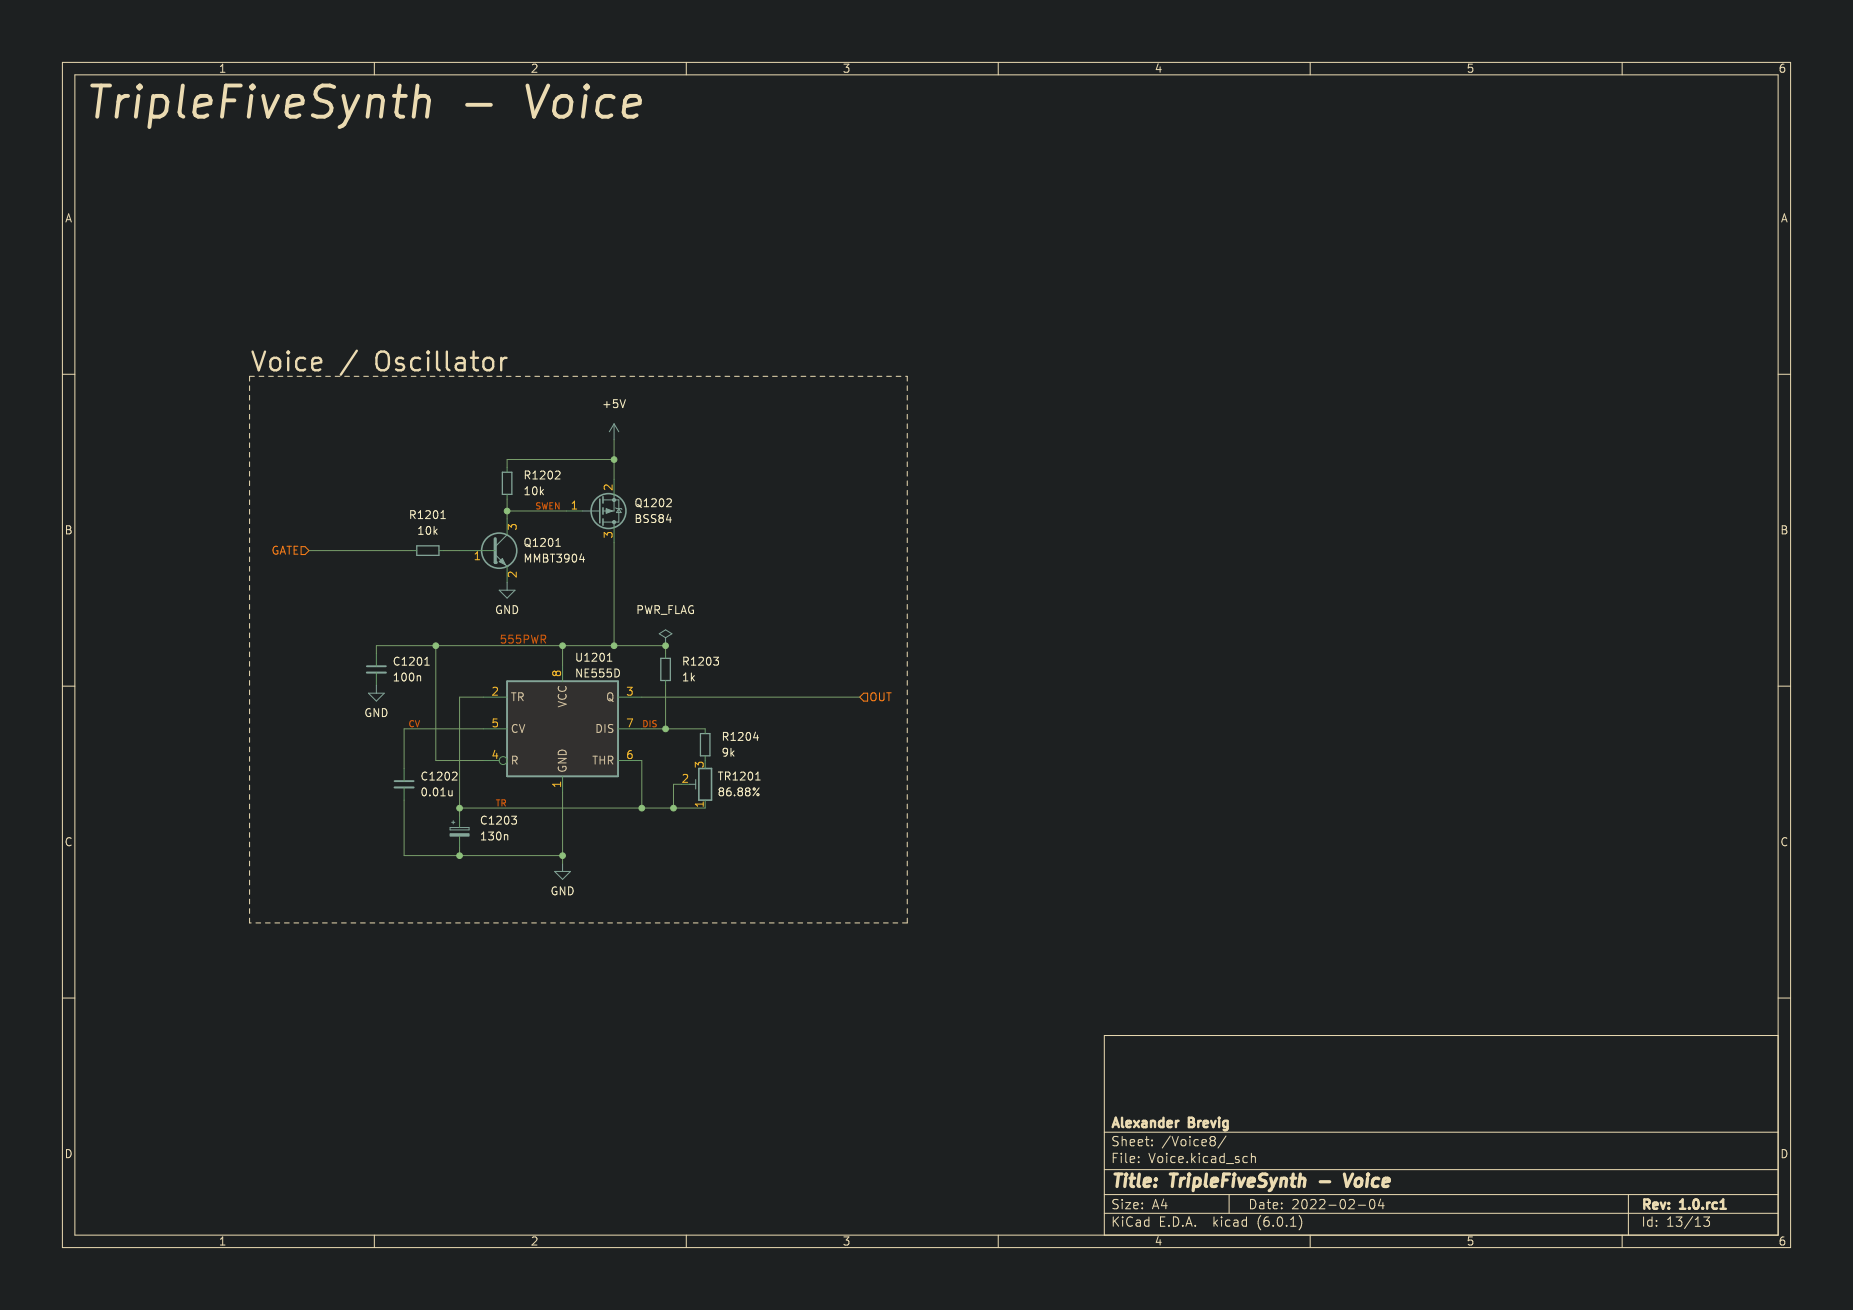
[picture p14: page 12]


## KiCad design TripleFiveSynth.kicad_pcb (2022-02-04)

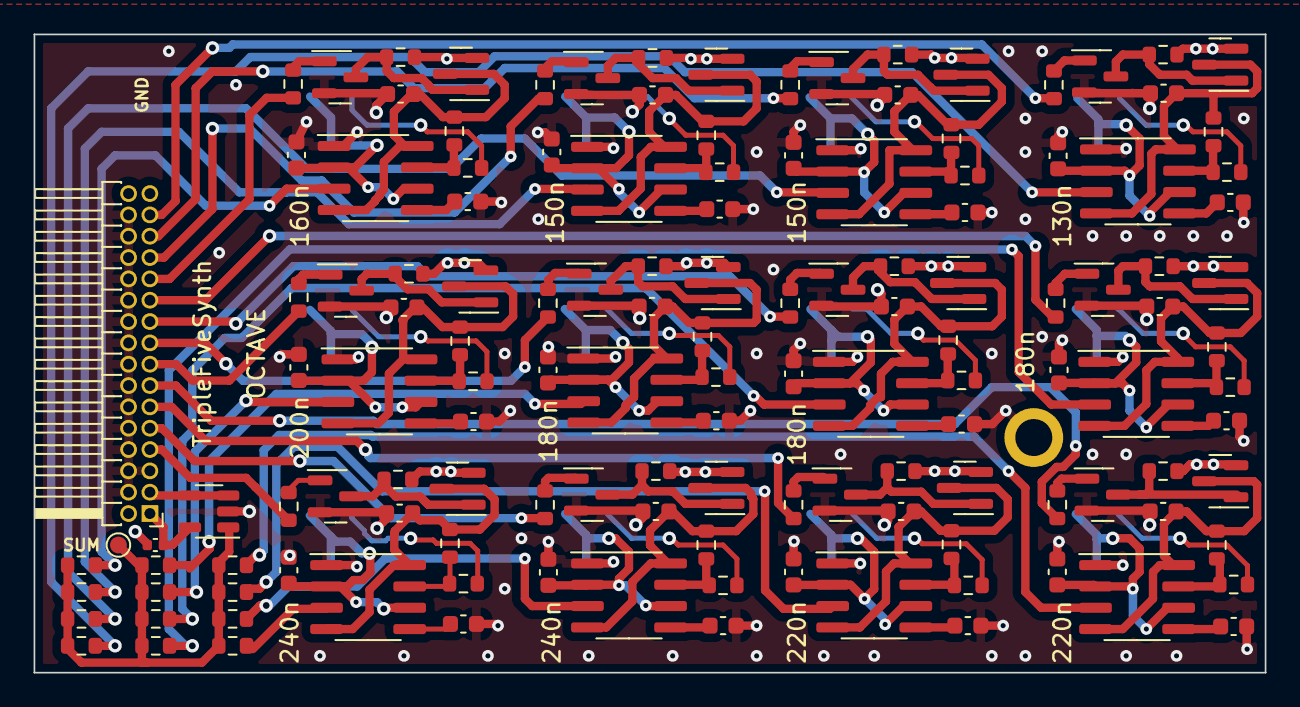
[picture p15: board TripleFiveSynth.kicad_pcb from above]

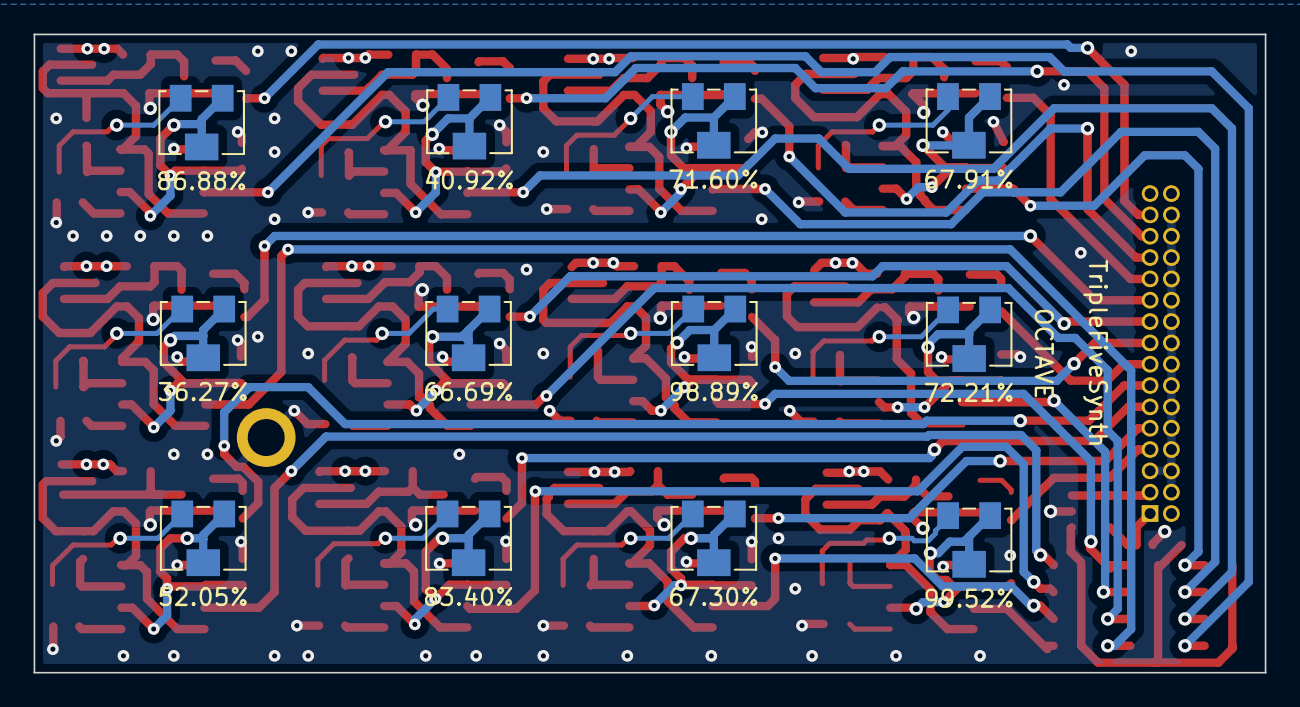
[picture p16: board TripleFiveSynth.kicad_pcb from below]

Board: 4 copper layers, 73.3 x 38.0 mm, 149 parts (12 on the bottom side), 112 nets.

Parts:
C101: 100n; C_0402_1005Metric
C201, C301, C401, C501, C601, C701, C801, C901, C1001, C1101, C1201, C1301: 100n; C_0603_1608Metric
C202, C302, C402, C502, C602, C702, C802, C902, C1002, C1102, C1202, C1302: 0.01u; C_0603_1608Metric
C203, C303, C403, C503, C603, C703, C803, C903, C1003, C1103, C1203, C1303: ${c_val}; C_0603_1608Metric
H101: MountingHole_Pad; MountingHole_2.2mm_M2_ISO7380_Pad
J101: OctaveIO; PinHeader_2x16_P1.27mm_Horizontal
Q201, Q301, Q401, Q501, Q601, Q701, Q801, Q901, Q1001, Q1101, Q1201, Q1301: MMBT3904; SOT-23
Q202, Q302, Q402, Q502, Q602, Q702, Q802, Q902, Q1002, Q1102, Q1202, Q1302: BSS84; SOT-23
R101, R102, R103, R104, R105, R106, R107, R108, R109, R110, R111, R112, R201, R202, R301, R302, R401, R402, R501, R502, R601, R602, R701, R702, R801, R802, R901, R902, R1001, R1002, R1101, R1102, R1201, R1202, R1301, R1302: 10k; R_0603_1608Metric
R203, R303, R403, R503, R603, R703, R803, R903, R1003, R1103, R1203, R1303: 1k; R_0603_1608Metric
R204, R304, R404, R504, R604, R704, R804, R904, R1004, R1104, R1204, R1304: 9k; R_0603_1608Metric
TP101: SUM; TestPoint_Pad_D1.0mm
TR201, TR301, TR401, TR501, TR601, TR701, TR801, TR901, TR1001, TR1101, TR1201, TR1301: ${r_val}; Potentiometer_Bourns_3224W_Vertical
U101: LMV321; SOT-23-5
U201, U301, U401, U501, U601, U701, U801, U901, U1001, U1101, U1201, U1301: NE555D; SOIC-8_3.9x4.9mm_P1.27mm

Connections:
+5V: C101.1, J101.1, J101.2, J101.31, J101.32, Q202.2 (S), Q302.2 (S), Q402.2 (S), Q502.2 (S), Q602.2 (S), Q702.2 (S), Q802.2 (S), Q902.2 (S), Q1002.2 (S), Q1102.2 (S), Q1202.2 (S), Q1302.2 (S), R202.1, R302.1, R402.1, R502.1, R602.1, R702.1, R802.1, R902.1, R1002.1, R1102.1, R1202.1, R1302.1, U101.5 (V+)
/GATEA: J101.25, R1101.2
/GATEAS: J101.27, R1001.2
/GATEB: J101.29, R1201.2
/GATEC: J101.7, R401.2
/GATECS: J101.9, R301.2
/GATED: J101.11, R201.2
/GATEDS: J101.13, R1301.2
/GATEE: J101.15, R501.2
/GATEF: J101.17, R701.2
/GATEFS: J101.19, R601.2
/GATEG: J101.21, R801.2
/GATEGS: J101.23, R901.2
/OUTA: R110.2, U1101.3 (Q)
/OUTAS: R111.2, U1001.3 (Q)
/OUTB: R112.2, U1201.3 (Q)
/OUTC: R101.2, U401.3 (Q)
/OUTCS: R102.2, U301.3 (Q)
/OUTD: R103.2, U201.3 (Q)
/OUTDS: R104.2, U1301.3 (Q)
/OUTE: R105.2, U501.3 (Q)
/OUTEG: R108.2, U801.3 (Q)
/OUTF: R106.2, U701.3 (Q)
/OUTFS: R107.2, U601.3 (Q)
/OUTGS: R109.2, U901.3 (Q)
/OUTSUM: J101.3, U101.3 (-), U101.4
/SUM: R101.1, R102.1, R103.1, R104.1, R105.1, R106.1, R107.1, R108.1, R109.1, R110.1, R111.1, R112.1, TP101.1, U101.1 (+)
/Voice1/555PWR: C301.1, Q302.3 (D), R303.2, U301.4 (R), U301.8 (VCC)
/Voice1/CV: C302.1, U301.5 (CV)
/Voice1/DIS: R303.1, R304.2, U301.7 (DIS)
/Voice1/SWEN: Q301.3 (C), Q302.1 (G), R302.2
/Voice1/TR: C303.1, TR301.1, TR301.2, U301.2 (TR), U301.6 (THR)
/Voice2/555PWR: C201.1, Q202.3 (D), R203.2, U201.4 (R), U201.8 (VCC)
/Voice2/CV: C202.1, U201.5 (CV)
/Voice2/DIS: R203.1, R204.2, U201.7 (DIS)
/Voice2/SWEN: Q201.3 (C), Q202.1 (G), R202.2
/Voice2/TR: C203.1, TR201.1, TR201.2, U201.2 (TR), U201.6 (THR)
/Voice3/555PWR: C1301.1, Q1302.3 (D), R1303.2, U1301.4 (R), U1301.8 (VCC)
/Voice3/CV: C1302.1, U1301.5 (CV)
/Voice3/DIS: R1303.1, R1304.2, U1301.7 (DIS)
/Voice3/SWEN: Q1301.3 (C), Q1302.1 (G), R1302.2
/Voice3/TR: C1303.1, TR1301.1, TR1301.2, U1301.2 (TR), U1301.6 (THR)
/Voice4/555PWR: C601.1, Q602.3 (D), R603.2, U601.4 (R), U601.8 (VCC)
/Voice4/CV: C602.1, U601.5 (CV)
/Voice4/DIS: R603.1, R604.2, U601.7 (DIS)
/Voice4/SWEN: Q601.3 (C), Q602.1 (G), R602.2
/Voice4/TR: C603.1, TR601.1, TR601.2, U601.2 (TR), U601.6 (THR)
/Voice5/555PWR: C501.1, Q502.3 (D), R503.2, U501.4 (R), U501.8 (VCC)
/Voice5/CV: C502.1, U501.5 (CV)
/Voice5/DIS: R503.1, R504.2, U501.7 (DIS)
/Voice5/SWEN: Q501.3 (C), Q502.1 (G), R502.2
/Voice5/TR: C503.1, TR501.1, TR501.2, U501.2 (TR), U501.6 (THR)
/Voice6/555PWR: C701.1, Q702.3 (D), R703.2, U701.4 (R), U701.8 (VCC)
/Voice6/CV: C702.1, U701.5 (CV)
/Voice6/DIS: R703.1, R704.2, U701.7 (DIS)
/Voice6/SWEN: Q701.3 (C), Q702.1 (G), R702.2
/Voice6/TR: C703.1, TR701.1, TR701.2, U701.2 (TR), U701.6 (THR)
/Voice7/555PWR: C801.1, Q802.3 (D), R803.2, U801.4 (R), U801.8 (VCC)
/Voice7/CV: C802.1, U801.5 (CV)
/Voice7/DIS: R803.1, R804.2, U801.7 (DIS)
/Voice7/SWEN: Q801.3 (C), Q802.1 (G), R802.2
/Voice7/TR: C803.1, TR801.1, TR801.2, U801.2 (TR), U801.6 (THR)
/Voice8/555PWR: C1201.1, Q1202.3 (D), R1203.2, U1201.4 (R), U1201.8 (VCC)
/Voice8/CV: C1202.1, U1201.5 (CV)
/Voice8/DIS: R1203.1, R1204.2, U1201.7 (DIS)
/Voice8/SWEN: Q1201.3 (C), Q1202.1 (G), R1202.2
/Voice8/TR: C1203.1, TR1201.1, TR1201.2, U1201.2 (TR), U1201.6 (THR)
/Voice9/555PWR: C901.1, Q902.3 (D), R903.2, U901.4 (R), U901.8 (VCC)
/Voice9/CV: C902.1, U901.5 (CV)
/Voice9/DIS: R903.1, R904.2, U901.7 (DIS)
/Voice9/SWEN: Q901.3 (C), Q902.1 (G), R902.2
/Voice9/TR: C903.1, TR901.1, TR901.2, U901.2 (TR), U901.6 (THR)
/Voice10/555PWR: C1101.1, Q1102.3 (D), R1103.2, U1101.4 (R), U1101.8 (VCC)
/Voice10/CV: C1102.1, U1101.5 (CV)
/Voice10/DIS: R1103.1, R1104.2, U1101.7 (DIS)
/Voice10/SWEN: Q1101.3 (C), Q1102.1 (G), R1102.2
/Voice10/TR: C1103.1, TR1101.1, TR1101.2, U1101.2 (TR), U1101.6 (THR)
/Voice11/555PWR: C1001.1, Q1002.3 (D), R1003.2, U1001.4 (R), U1001.8 (VCC)
/Voice11/CV: C1002.1, U1001.5 (CV)
/Voice11/DIS: R1003.1, R1004.2, U1001.7 (DIS)
/Voice11/SWEN: Q1001.3 (C), Q1002.1 (G), R1002.2
/Voice11/TR: C1003.1, TR1001.1, TR1001.2, U1001.2 (TR), U1001.6 (THR)
/Voice/555PWR: C401.1, Q402.3 (D), R403.2, U401.4 (R), U401.8 (VCC)
/Voice/CV: C402.1, U401.5 (CV)
/Voice/DIS: R403.1, R404.2, U401.7 (DIS)
/Voice/SWEN: Q401.3 (C), Q402.1 (G), R402.2
/Voice/TR: C403.1, TR401.1, TR401.2, U401.2 (TR), U401.6 (THR)
GND: C101.2, C201.2, C202.2, C203.2, C301.2, C302.2, C303.2, C401.2, C402.2, C403.2, C501.2, C502.2, C503.2, C601.2, C602.2, C603.2, C701.2, C702.2, C703.2, C801.2, C802.2, C803.2, C901.2, C902.2, C903.2, C1001.2, C1002.2, C1003.2, C1101.2, C1102.2, C1103.2, C1201.2, C1202.2, C1203.2, C1301.2, C1302.2, C1303.2, H101.1, J101.4, J101.5, J101.6, J101.8, J101.10, J101.12, J101.14, J101.16, J101.18, J101.20, J101.22, J101.24, J101.26, J101.28, J101.30, Q201.2 (E), Q301.2 (E), Q401.2 (E), Q501.2 (E), Q601.2 (E), Q701.2 (E), Q801.2 (E), Q901.2 (E), Q1001.2 (E), Q1101.2 (E), Q1201.2 (E), Q1301.2 (E), U101.2 (V-), U201.1 (GND), U301.1 (GND), U401.1 (GND), U501.1 (GND), U601.1 (GND), U701.1 (GND), U801.1 (GND), U901.1 (GND), U1001.1 (GND), U1101.1 (GND), U1201.1 (GND), U1301.1 (GND)
unnamed: Q201.1 (B), R201.1
unnamed: Q301.1 (B), R301.1
unnamed: Q401.1 (B), R401.1
unnamed: Q501.1 (B), R501.1
unnamed: Q601.1 (B), R601.1
unnamed: Q701.1 (B), R701.1
unnamed: Q801.1 (B), R801.1
unnamed: Q901.1 (B), R901.1
unnamed: Q1001.1 (B), R1001.1
unnamed: Q1101.1 (B), R1101.1
unnamed: Q1201.1 (B), R1201.1
unnamed: Q1301.1 (B), R1301.1
unnamed: R204.1, TR201.3
unnamed: R304.1, TR301.3
unnamed: R404.1, TR401.3
unnamed: R504.1, TR501.3
unnamed: R604.1, TR601.3
unnamed: R704.1, TR701.3
unnamed: R804.1, TR801.3
unnamed: R904.1, TR901.3
unnamed: R1004.1, TR1001.3
unnamed: R1104.1, TR1101.3
unnamed: R1204.1, TR1201.3
unnamed: R1304.1, TR1301.3

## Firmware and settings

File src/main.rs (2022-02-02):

use std::collections::HashSet;
use std::hash::Hash;
use std::io::Write;
use std::fs::File;

const PICO_VALS: [f64; 24] = [1.0, 1.1, 1.2, 1.3, 1.5, 1.6, 1.8, 2.0, 2.2, 2.4, 2.7, 3.0, 3.3, 3.6, 3.9, 4.3, 4.7, 5.1, 5.6, 6.2, 6.8, 7.5, 8.2, 9.1];
const HZ: [f64; 108] = [16.35, 17.32, 18.35, 19.45, 20.60, 21.83, 23.12, 24.50, 25.96, 27.50, 29.14, 30.87, 32.70, 34.65, 36.71, 38.89, 41.20, 43.65, 46.25, 49.00, 51.91, 55.00, 58.27, 61.74, 65.41, 69.30, 73.42, 77.78, 82.41, 87.31, 92.50, 98.00, 103.83, 110.00, 116.54, 123.47, 130.81, 138.59, 146.83, 155.56, 164.81, 174.61, 185.00, 196.00, 207.65, 220.00, 233.08, 246.94, 261.63, 277.18, 293.66, 311.13, 329.63, 349.23, 369.99, 392.00, 415.30, 440.00, 466.16, 493.88, 523.25, 554.37, 587.33, 622.25, 659.25, 698.46, 739.99, 783.99, 830.61, 880.00, 932.33, 987.77, 1046.50, 1108.73, 1174.66, 1244.51, 1318.51, 1396.91, 1479.98, 1567.98, 1661.22, 1760.00, 1864.66, 1975.53, 2093.00, 2217.46, 2349.32, 2489.02, 2637.02, 2793.83, 2959.96, 3135.96, 3322.44, 3520.00, 3729.31, 3951.07, 4186.01, 4434.92, 4698.63, 4978.03, 5274.04, 5587.65, 5919.91, 6271.93, 6644.88, 7040.00, 7458.62, 7902.13];

const DELTA:f64 = 0.0000000000001;
const PICO: f64 = 0.000000000001;
const NANO: f64 = 0.000000001;
const MICRO: f64 = 0.000001;
const TRIM_MAX:f64 = -1000.0;
const TRIM_MIN:f64 = 1000.0;

fn find_min_max_trim(freq:f64, cap:usize, base_unit:f64) -> (f64,f64,f64,f64) {
    let c1: f64 =   PICO_VALS[cap] * base_unit;

    let min:f64 = find_width_trim(c1, TRIM_MIN);
    let max:f64 = find_width_trim(c1, TRIM_MAX);
    let (best_trim, best_freq) = find_trim_and_freq(c1, freq);

    return (min,max,best_trim,best_freq);
}

fn find_width_trim(c1:f64, trim:f64) -> f64 {
    let r1: f64 = 1000.0;
    let r2: f64 = 10000.0+trim;

    let t1: f64 = 0.693 * (r1+r2) * c1; 
    let t2: f64 = 0.693 * r2 * c1;
    //let f:f64 = (1.0/(t1 + t2)*100.0).round() / 100.0;
    let f:f64 = 1.0/(t1 + t2);
    return f;
}
// No python here my dude 
fn find_trim_and_freq(c1:f64, f:f64) -> (f64,f64) {
    let mut trim:f64 = 1000.0;
    let delta:f64 = 0.1;
    let mut best_delta:f64 = 100000.0;
    let mut best_trim:f64 = 0.0;
    let mut best_freq:f64 = 0.0;
    while trim>=-1000.0 {
        let f_found = find_width_trim(c1, trim);

        let freq_delta = (f_found - f).abs();
        if freq_delta < best_delta {
            best_delta = freq_delta;
            best_trim = trim;
            best_freq = f_found;
        }
        if freq_delta <= 0.005{
            break;
        }
        trim -= delta;
    }
    best_trim = (best_trim*100.0).round()/100.0;
    best_freq = (best_freq*100.0).round()/100.0;
    return (best_trim, best_freq);
}

fn find(freq:f64, note:usize, cap:usize, base_unit:f64) -> Result<(f64, f64,f64,f64), &'static str>{
    let (min,max,trim,freq_result) = find_min_max_trim(freq, cap, base_unit);
    if min <= HZ[note] && max >= HZ[note] {
        return Ok((min, max, trim, freq_result));
    } else {
        return Err("Could not find match for note");
    }
}

#[derive(Hash, Debug)]
struct Cap {
    value: u32,
    unit: String,
}
impl PartialEq for Cap {
    fn eq(&self, other: &Self) -> bool {
        self.value == other.value && self.unit == other.unit
    }
}
impl Eq for Cap {}


fn main() -> std::io::Result<()> {
    println!("CAPACITOR & TRIM CALCULATOR FOR 555 SYNTH:\n\n");
    let file_name = "tune_triple_fives.txt";
    println!("Writing to file `{}`", file_name);
    let mut file = File::create(file_name)?;
    let mut found = 0;
    let mut capvals = HashSet::new();
    let mut min_trim = TRIM_MIN; // Seems backwards, but it is correct
    let mut max_trim = TRIM_MAX;
    for (i,freq) in HZ.iter().enumerate() {
        let mut found_match = false;
        for (_, unit) in [MICRO, NANO, PICO].iter().enumerate() {
            for (_, multiplier) in [1.0,10.0,100.0].iter().enumerate() {
                for (v, value) in PICO_VALS.iter().enumerate() {
                    //println!("freq #{}:{}, value #{}:{}, unit #{}:{}", i,freq,v,value,u,unit);
                    match find(*freq, i, v, *unit * multiplier) {
                        Ok((_min,_max,trim,_best_freq)) => {
                            let unitstr:&str = match unit {
                                x if x >= &(&MICRO-DELTA) && x <= &(&MICRO+DELTA) => "u",
                                x if x >= &(&NANO-DELTA) && x <= &(&NANO+DELTA) => "n",
                                x if x >= &(&PICO-DELTA) && x <= &(&PICO+DELTA) => "p",
                                _ => "",
                            };
                            // Keep inventory of used capacitor values
                            capvals.insert( Cap{ value: (*value*multiplier).round() as u32,unit: unitstr.to_string()});
                            // Print information for layout
                            file.write_fmt(format_args!("{:07.2}Hz => {:06.2}{}F\tTrim => {:06.1}Ω -> {:05.2}%\n", freq, (value*multiplier*100.0).round()/100.0, unitstr, ((1000.0+trim)*100.0).round()/100.0, (((1000.0+trim)/2000.0)*10000.0).round()/100.0))?;

                            found_match = true;
                            found += 1;
                            if trim < min_trim {
                                min_trim = trim;
                            } else if trim > max_trim {
                                max_trim = trim;
                            }
                            break;
                        },
                        Err(_)=> {},
                    }
                }
            }
        }
        if !found_match {
            println!("ERROR: No match for #{}:{}", i, freq)
        }
    }
    println!("Found {}", found);
    println!("Capacitor values #{}", capvals.len());
    println!("Trim from {} to {}", min_trim, max_trim);
    /*for capval in &capvals {
        println!("{:?}", capval)
    }*/
    Ok(())
}

#[test]
fn test_known_good_c0() {
    let res = find(16.35, 0, 14, MICRO).unwrap();
    assert_eq!(16.35, res.3);
    assert_eq!(815.0, res.2);
}

#[test]
fn test_known_good_a4() {
    let res = find(440.0, 57, 4, NANO * 100.0).unwrap();
    assert_eq!(440.0, res.3);
    assert_eq!(431.8, res.2);
}

#[test]
fn test_known_good_b8() {
    let res = find(7902.13, 107, 22, NANO).unwrap();
    assert_eq!(7902.13, res.3);
    assert_eq!(634.7, res.2);
}

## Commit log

2022-02-02 initial commit, cap + trim calc working
    [TripleFiveSynth.kicad_sch]
2022-02-02 add note for tuning 440Hz
2022-02-02 ERC and DRC 0 errors
    [TripleFiveSynth.kicad_pcb, TripleFiveSynth.kicad_sch, Voice.kicad_sch]
2022-02-02 swap to SMD Bourns 3224W, can stack in Eurorack now
    [Bourns 3324W Trimpot.step, TripleFiveSynth.kicad_pcb, TripleFiveSynth.kicad_sch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]
2022-02-04 sim with correct components, and 5V
2022-02-04 update with 5V and on-board sum
    [TripleFiveSynth.kicad_pcb, TripleFiveSynth.kicad_sch, Voice.kicad_sch]
2022-02-04 add schematic for easier review
